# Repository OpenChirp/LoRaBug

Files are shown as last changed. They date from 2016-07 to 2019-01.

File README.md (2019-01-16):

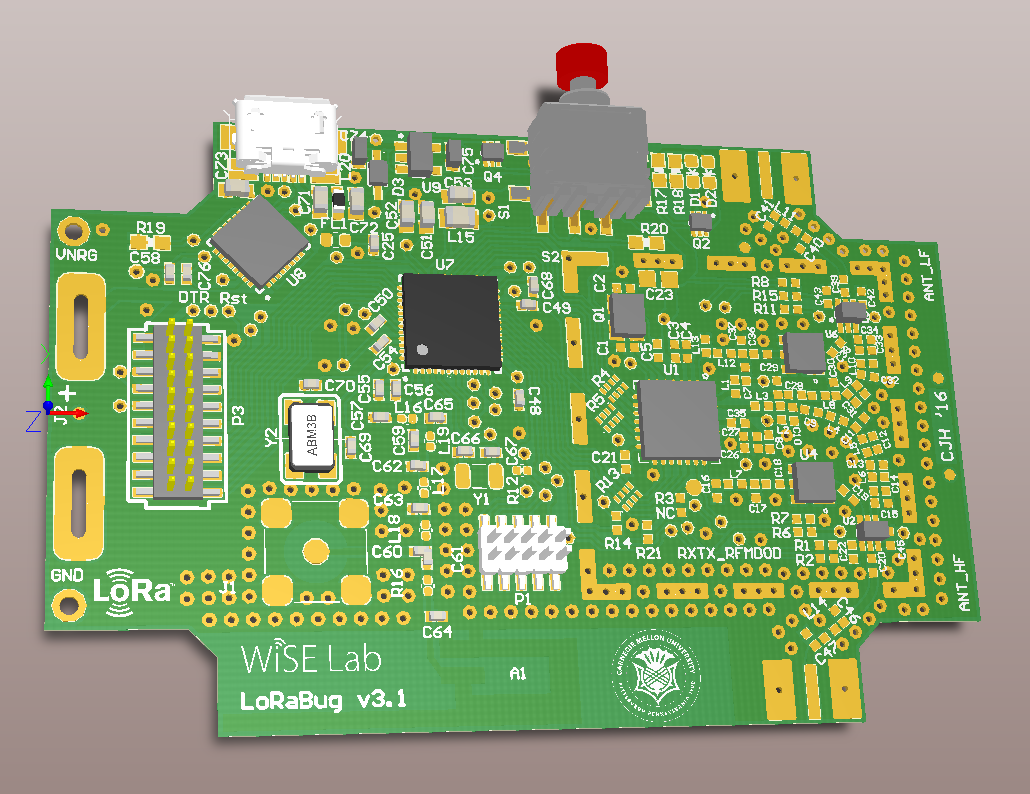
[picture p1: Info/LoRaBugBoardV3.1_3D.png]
LoRaBugBoard V3.1 3D Picture


# Specs
* TI CC2650 MCU with BLE and 802.15.4 support
* SX1276 LoRa radio
* Provide 500mA 3.3V (3.3-3.4V) from USB.

# Board Details
* Pin mappings are detailed in the spreadsheet found [here](https://docs.google.com/spreadsheets/d/1lk55i37ZrpTx_7zy1oA4uAmHo3XsjOCir2L95xEN9fU/edit?usp=sharing).
* Board physical dimensions and header placement can be found [here](https://docs.google.com/drawings/d/1snO6Dwncqp3OL73APsFgQn0SESudZwlPjw8W5KeOZVo/edit?usp=sharing).
* You can find other information, such as the schematic and board renderings, in the [Info](Info/) directory.

# Firmware Notes
* You can detect the presence of a USB by checking if the FTDI TX and RX
  pins are high. When the FTDI chip is activated, it pulls the TX and RX
  lines high.
  Additionally, this means the CC2650 should use push/pull and no pull-ups 
  when communicating with the FTDI.

# Info
* The power supported by the USB is limited by the 500mA limit of diode D3 and the 600mA limit of the voltage regulator U9.
* When using USB power, the 3.3V rail may swing to 3.4V. This is due to the linear regulator's ground pin voltage being raised by the inline mosfet Q4.
* The SX1276 is said to be only able to support PA_BOOST +20dBm TX when the input voltage is greater than 2.4V. See section 5.4.3 in the [SX1276 datasheet][sx1276_datasheet].

# Low Power Profile
Other than the reverse leakage current, these values are totally unconfirmed. The values are pulled straight from the [datasheet][sx1276_datasheet].

* Reverse leakage from battery through voltage regulation circuitry has shown to draw upwards of **80 nA**. Based on the datasheets, there is a possibility of 0.1 - 0.2uA draw.
* [CC2650][cc2650_overview]
    - Normal operation between 1.8 V and 3.8 V
    - The main MCU crystal is 24 MHz, which is doubled internally. There is also a 32 kHz clock for BLE. See section 6.9 in [overview datasheet][cc2650_brief_datasheet].
    - Active-Mode draws **61 uA/MHz**
    - Active-Mode Sensor Controller draws **8.2 uA/MHz**
    - Standby draws **1 uA** (RTC Running and RAM/CPU Retention)
    - Shutdown draws **100 nA** (Wake Up on External Events)
    - Active-Mode RX draws **5.9 mA**
    - Active-Mode TX at 0 dBm draws **6.1 mA**
    - Active-Mode TX at +5dBm draws **9.1 mA**
    - The sensor controller(when cpu freq. scalled) consumes less power than the [MSP430G2X][msp430_overview], which consumes 220 uA/MHz in active-mode and 0.7 uA in RTC mode.
* [SX1276][sx1276_overview]
    - Up to +17 dBm of RF output power which is maintained from 1.8 V to 3.7 V and +20 dBm from 2.4 V to 3.7 V. See section 5.1 of [datasheet][sx1276_datasheet].
    - We have PA_BOOST connected to the HF (high frequency) side antenna. This means we output 915MHz HF signals through PA_BOOST.
    - LoRa HF RX mode draws **10.3 mA**(125kHz bw) or **12.6 mA**(500kHz bw) with LNABoost off. See sections 2.5.1 and 2.5.5 of [datasheet][sx1276_datasheet].
    - LoRa HF TX mode draws around **90 mA** for +17dBm PA_BOOST and somewhere around **120 mA** for +20dBm PA_BOOST.
    - Sleep mode draws **0.2 uA**
    - Idle mode (RC oscillator enabled) draw **1.5 uA**
    - Standby mode (Crystal oscillator enabled) draw **1.6 mA**

# Changelog
* V3.1
    - Removed inverter and pullup/pulldown resistors from LoRa radio module for power saving
    - Mapped RF_CTRL1 and RF_CTRL2 as complement control pair for RF switches for power saving
    - Resolved SX1276 crystal caps manufacturing issue
* V3
    - Changed IO header to a 20pin 1.27mm for ease of use
    - Access to VCC_NREG, the power feeding the onboard regulator
    - Active low button
    - FTDI TX/RX lines pulled into header
    - Removed onboard I2C resistors
* V2
    - Fixed button NC/NO leads. Pulldown now pulls the signal low as initially designed.
    - Fixed leakage current through the linear regulator
    - Changed FTDI footprint to have longer leads for hand soldering
    - Used a single dual N-channel mosfet chip to control LEDs
    - Changed the fiducial location
    - Changed some components to consolidate count
* V1 - Initial Release

# Contribution Info

## Generating Manufacturer Files
To generate the manufacturer files for APCircuits.com, you need to generate the Gerbers(with outline), Aperture file, and NC Drill file.

To generate the gerbers and aperture files, do the following:
1. Click File -> Fabrication Output -> Gerber Files, when viewing a PCB Layout.
2. Make sure that Top Overlay, Top Paste, Top Solder, Top Layer, Bottom Layer, Bottom Solder, Bottom Overlay(optional), and Mechanical 1 are selected in the Layers tab.
3. Do not have anything selected in the Drill Drawing tab, and make sure that "Embedded aperture (RS274X)" is selected in the Aperture tab.
4. Press Ok.

To generate the NC Drill File, do the following:
1. Click File -> Fabrication Output -> NC Drill Files, when viewing a PCB Layout.
2. Just click Ok to the default settings.

To generate the pick and place coordinates file:
1. Click File -> Assembly Outputs -> Generate pick and place files
2. Ensure only the Text and Imperial options are checked and click Ok

The previous operations place all the output files in the "Project Output for LoRaBugBoard" directory.
You now just need to combine the following list of file into a zip archive. Make sure to copy in the
README.txt from previous archives.

Archive File List:

* PCBFireflyCaseV3.apr
* PCBFireflyCaseV3.DRR
* PCBFireflyCaseV3.GBL
* PCBFireflyCaseV3.GBO
* PCBFireflyCaseV3.GBS
* PCBFireflyCaseV3.GM1
* PCBFireflyCaseV3.GTL
* PCBFireflyCaseV3.GTO
* PCBFireflyCaseV3.GTP
* PCBFireflyCaseV3.GTS
* PCBFireflyCaseV3-RoundHoles.TXT
* PCBFireflyCaseV3-SlotHoles.TXT
* Pick Place for PCBFireflyCaseV3.txt
* README.txt

## Testing the Hardware
* ***Test FTDI, System UART, Bootloader Backdoor Trigger, and Onboard Voltage Regulator***
  Ensure that the bootloader backdoor is configured to use the button. Ensure R20 is low enough to not trigger the bootloader after reset.
  I previously had an issue where the pulldow(at the time) wasn't strong enough. Next, ensure you can actually enter the bootloader during reset.
  To aid in this, I created a script called [trigger_bootloader.sh](Info/trigger_bootloader.sh) in the Info directory that sends the initialization
  bytes to serial repeatedly. If you cat the serial device at the same time, you should see the bootloader respond.
  Maybe do a `stty -F /dev/ttyUSB0 115200 && cat /dev/ttyUSB0 | hd`. Checkout the [CC2650 Bootloader Spec][cc2650_bootloader_spec].
* ***Test LEDs***
* ***Test Pins in GPIO Hedaer***
* ***Test Debugging CC2650 Over Cortex Debug Header***
* ***Test SX1276 Front End***

# Antennas

| Description | Part Name | Manufacturer | Connector |
| ---| --- | --- | --- |
| Standard yellow 915MHz LoRa 5.591" 1.2dBi | [NT-916-CW-HWR-SMA](http://www.linxtechnologies.com/resources/data-guides/ant-916-cw-hwr.pdf) | Linx Technologies | SMA-Male |
| ~~4.256" 900MHz 3.0dBi~~ | ~~[APAMS-118](http://abracon.com/external-antenna/APAMS-118.pdf)~~ | ~~Abracon LLC~~ | ~~SMA-Male~~ |

# Accessories

The board was designed to accept an **RFI shield** over the LoRa radio components.
You can solder on a static can or use the two part removable can.
* Static can [BMI-S-103](http://www.digikey.com/products/en?keywords=BMI-S-103). The preferred low-profile can is the BMI-S-111 by Laird.
* Removable two part: The frame is [BMI-S-203-F](http://www.digikey.com/products/en?keywords=BMI-S-203-F) and the cover is [BMI-S-203-C](http://www.digikey.com/products/en?keywords=BMI-S-203-C).
* You can use a 10pin 1.27mm female-to-female IDC cable to connect the CC2650 Launchpad debugger.
  One such cable is the [Harwin M50 Female-to-Female](https://www.digikey.com/product-detail/en/harwin-inc/M50-9100542/952-2568-ND/4953091) cable.
* The SensorBug board uses a Tag-Connect TC2030 pin interface to pass JTAG through to the LoRaBug.
  You can use the [TC2030-CTX](http://www.tag-connect.com/TC2030-CTX) cable to connect the
  CC2650 Launchpad debugger.

The I/O header is a standard 1.27mm 2x10 pin header.
You can use the [Harwin M50-3121045](http://www.digikey.com/products/en?keywords=M50-3121045) to interface with it.

[cc2650_overview]: http://www.ti.com/product/CC2650
[cc2650_brief_datasheet]: http://www.ti.com/lit/ds/symlink/cc2650.pdf
[sx1276_overview]: http://www.semtech.com/wireless-rf/rf-transceivers/sx1276/
[sx1276_datasheet]: http://www.semtech.com/images/datasheet/sx1276_77_78_79.pdf
[msp430_overview]: http://www.ti.com/lsds/ti/microcontrollers_16-bit_32-bit/msp/ultra-low_power/msp430g2x_i2x/overview.page
[cc2650_bootloader_spec]: http://www.ti.com/lit/an/swra466a/swra466a.pdf

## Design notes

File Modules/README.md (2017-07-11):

# Description
This directory contains contributed extension modules for the LoRaBug.

| Module | Description | Author |
|---|---|---|
| [RGBW IO Board](LoRaBUG_RGBW_DaughterBoard) | High-power 12V RGBW LED Strip Controller with buttons and RGB LED | [Artur Balanuta](https://github.com/ABalanuta) |
| [SensorBug Board](SensorBug) | Environmental sensor board with a Grid-EYE IR sensor array | [Abhinand Sukumar](https://github.com/abhinans) |

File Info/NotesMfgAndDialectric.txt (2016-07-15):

Trace Thickness:      1       oz/ft^2
Substrate Height:     62      mil
Trace Width:          113.25  mil
Substrate dialectric: 4.58    
Impedance:            50Ohms

1oz/ft^2 == 1.4mil == 35.6um

####### AP Circuits #########

Drill Sizes
------------------------
Inch :(in mils) :x1.75
------------------------
.0200 (20   mil) 35
.0280 (28   mil) 49
.0350 (35   mil) 61.25
.0380 (38   mil) 66.5
.0420 (42   mil) 73.5
.0520 (52   mil) 91
.0595 (59.5 mil) 104.125
.0860 (86   mil) 150.5
.1250 (125  mil) 218.75
.1520 (152  mil) 266

BMI-S-103
BMI-S-203-F 26.21X26.21 (2PARTS)

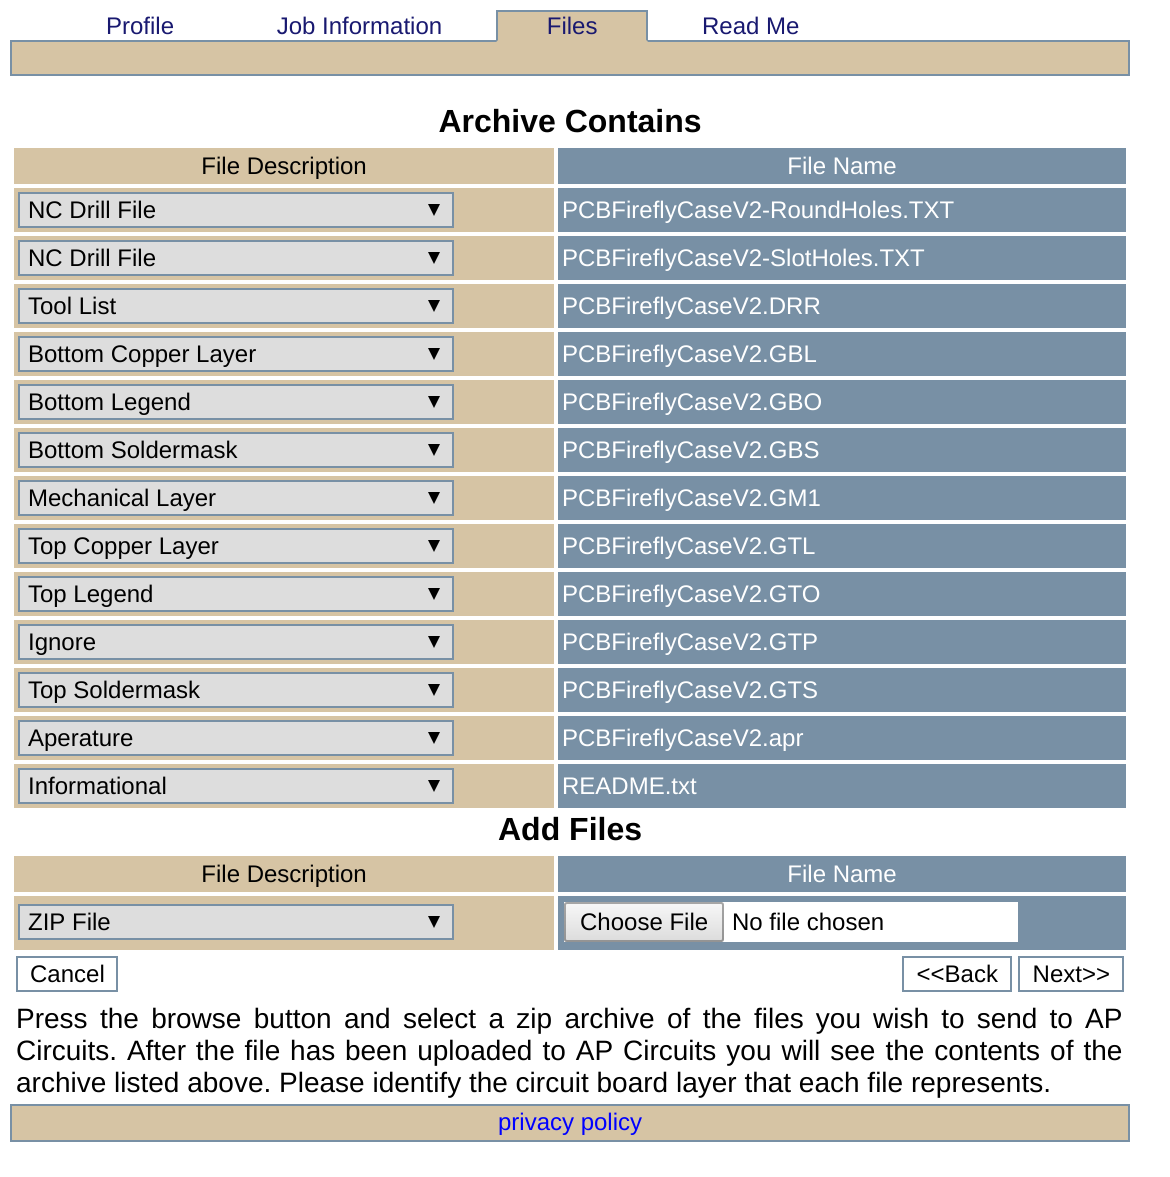
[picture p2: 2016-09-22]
Info/APCircuitsFiles.png

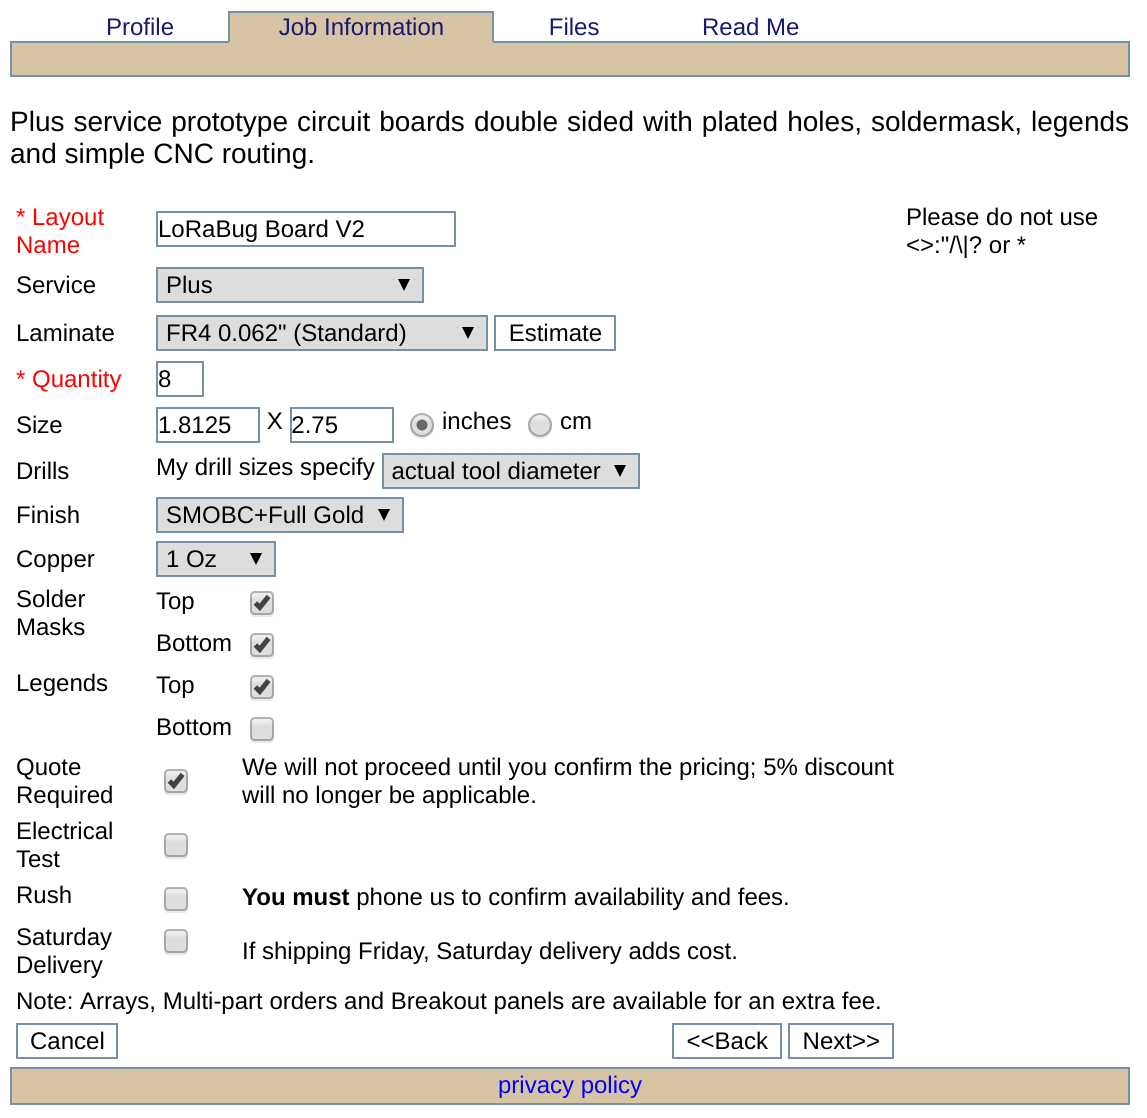
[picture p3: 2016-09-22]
Info/APCircuitsJobInformation.png

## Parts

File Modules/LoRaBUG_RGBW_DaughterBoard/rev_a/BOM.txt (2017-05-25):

Description			URL
LED RGB DIFFUSED 4SMD		https://www.digikey.com/product-detail/en/cree-inc/CLMVB-FKA-CFHEHLCBB7A363/CLMVB-FKA-CFHEHLCBB7A363CT-ND/6138627
Debug Connector Female		https://www.digikey.com/product-detail/en/harwin-inc/M50-3100545/952-1798-ND/3727767
Debug Connector Male		https://www.digikey.com/product-detail/en/harwin-inc/M50-3600542/952-1389-ND/2264370
475 Ohm Resistor 0603		https://www.digikey.com/product-detail/en/panasonic-electronic-components/ERJ-PA3J471V/P470BZCT-ND/5036331
10uF 0603 10V			https://www.digikey.com/product-detail/en/murata-electronics-north-america/GRM188R61A106KE69J/490-14372-1-ND/6606833
10uF 0603 25V			https://www.digikey.com/product-detail/en/murata-electronics-north-america/GRM188R61E106MA73D/490-7202-1-ND/3900486
MOSFET 2N-CH 30V 40A		https://www.digikey.com/product-detail/en/nexperia-usa-inc/BUK9K5R1-30EX/1727-2468-1-ND/5725903
IC REG LDO 3.3V 1A SOT223	https://www.digikey.com/product-detail/en/richtek-usa-inc/RT9164A-33GG/1028-1063-1-ND/3077883
DIODE SCHOTTKY 30V 500MA SOD323	https://www.digikey.com/product-detail/en/on-semiconductor/NSR0530HT1G/NSR0530HT1GOSCT-ND/5761654
SWITCH TACT SPST-NO 0.02A 12V 3.30mm x 3.10mm	https://www.digikey.com/product-detail/en/citizen/LS38G5-T/1642-1315-1-ND/5820730
CONN 6POS 2.54MM SES 		https://www.digikey.com/product-detail/en/te-connectivity-amp-connectors/1-2834016-6/A123832-ND/5872948
CONN 5.0MM SIDE ENTRY MSC 2P_GY	https://www.digikey.com/product-detail/en/te-connectivity-amp-connectors/2834095-1/A124212-ND/6012659
CONN RCPT 10POS SMD 1.27MM GOLD	https://www.digikey.com/product-detail/en/harwin-inc/M50-3100545/952-1798-ND/3727767
CONN HDR 1.27MM SMD AU 10POS	https://www.digikey.com/product-detail/en/harwin-inc/M50-3600542/952-1389-ND/2264370

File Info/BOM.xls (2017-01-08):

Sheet: Main, Power, and Peripherals
Identifier | Value | Geometry | Quantity | Description | Manufacturer Part Number | Manufacturer | Notes
PERIPH Q2 MAIN Q4 |  | SOT-563, SOT-666 | 2 | MOSFET 2N-CH 60V 0.1A SSMINI6 | FC6946010R | PANASONIC ELECTRONIC COMPONENTS (VA)
PERIPH D1 GREEN |  | 0603 | 1 | LED GREEN CLEAR 0603 SMD | 150060GS75000 | WURTH ELECTRONICS INC (VA)
PERIPH D2 RED |  | 0603 | 1 | LED RED CLEAR 0603 SMD | 150060RS75000 | WURTH ELECTRONICS INC (VA)
PWR D3 |  | SC-79, SOD-523 | 1 | DIODE SCHOTTKY 45V 750MA SC79-2 | BAS 52-02V H6327 | Infineon Technologies | 60-80 nA reverse leakage, but $0.47. Check Part Options for more choices
PERIPH S1 |  |  | 1 | SWITCH PUSH SPDT 0.4VA 28V | G3B15AH-XC | NKK SWITCHES
PERIPH P3 |  |  | 1 | Header 1.27mm 2x5 SMT Low-Profile | M50-3601042 | Harwin Inc. | New for V3
PWR U9 |  | SC-74A, SOT-753 | 1 | IC REG LDO 3.3V 0.6A SOT-25 | AP7365-33WG-7 | DIODES INCORPORATED (VA)
MAIN C76 (arduino rst) | 100pF | 0402 | DNM | CAP CER 100PF 50V NP0 0402 | GRM1555C1H101JA01D | MURATA ELECTRONICS (VA) | Use when you want an Arduino style reset when USB serial session starts
PWR C74 C75 | 1uF | 0603 | 2 | CAP CER 1UF 16V X5R 0603 | GRM188R61C105KA93D | MURATA ELECTRONICS (VA)
PERIPH R18 75OHM (Green LED D1) | 75 | 0603 | 1 | RES SMD 75 OHM 5% 1/10W 0603 | RC0603JR-0775RL | YAGEO (VA)
PERIPH R17 100OHM (Red LED D2) | 100 | 0603 | 1 | RES SMD 100 OHM 5% 1/10W 0603 | RC0603FR-07100RL | YAGEO (VA)
PERIPH R20 | 2.7K | 0603 | 1 | RES SMD 2.7K OHM 5% 1/10W 0603 | RMCF0603JT2K70 | STACKPOLE ELECTRONICS INC (VA) | Used to pull button high for bootloader backdoor trigger
PWR R19 | 47K | 0603 | 1 | RES SMD 47K OHM 5% 1/10W 0603 | RMCF0603JT47K0 | STACKPOLE ELECTRONICS INC (VA)

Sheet: FTDI
Identifier | Value | Geometry | Quantity | Description | Manufacturer Part Number | Manufacturer | Notes
FTDI U8 |  | 32-QFN | 1 | IC USB FS SERIAL UART 32-QFN | FT232RQ-REEL | FTDI (VA)
FTDI P2 (USB) |  |  | 1 | CONN USB MICRO B RECPT SMT R/A | 10118192-0001LF | AMPHENOL FCI (VA)
FTDI L20 (FERRITE) |  | 0603 | 1 | FERRITE BEAD 62 OHM 0603 1LN | 782633620 | WURTH ELECTRONICS INC (VA)
FTDI C71 C72 C73 | 100pF | 0603 | 3 | CAP CER 100PF 50V NP0 0603 | C0603C101J5GACTU | KEMET (VA)

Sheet: LoRa Radio Module Sorted
Identifier | Value | Geometry | Quantity | Description | Manufacturer Part Number | Manufacturer | Notes
ANT_HF ANT_LF |  | SMA End Launch 50 Ohms | 1 | SMA End launch jack receptacle for PCB mount Emerson Network | 142-0711-821 | Power | Only need 1 for 915MHz HF side
U4 U6 | 0R | 603 | 2 | Thick Film Resistor ±5%, 1/10W | CRCW06030000Z0EA | Vishay/Dale
R4 R5 R13 | 100R | EXB28V | 3 | SMD Resistor Array Resistors (4x), ±5%, 31mW | EXB-N8V101JX | Panasonic - ECG
R14 | 100R | 402 | 1 | Thick Film Resistor ±5%, 1/16W | CRCW0402100RJNED | Vishay/Dale
R2 R6 R11 R15 | 1k | 402 | 4 | Thick Film Resistor ±5%, 1/16W | CRCW04021K00JNED | Vishay/Dale
C1 C2 | 15pF | 402 | 2 | Multilayer ceramic capacitors C0G ±5%, 50V for Rakon Crystal (18pF for NDK) | GRM1555C1H150JA01D | Murata | Changed back to 15pF from 10pF, since 10pF does not work
C3 C4 C5 C21 C27 | 100nF | 402 | 5 | Multilayer ceramic capacitors X7R ±10%, 16V | GRM155R71C104KA88D | Murata
C10 C11 C29 | 8.2pF | 402 | 3 | Multilayer ceramic capacitors C0G ±5%, 50V | GRM1555C1H8R2CA01D | Murata
C7 | 100pF | 402 | 1 | Multilayer ceramic capacitors C0G ±5%, 50V | GRM1555C1H101JA01D | Murata
C32 | 12pF | 402 | 1 | Multilayer ceramic capacitors C0G ±5%, 50V | GRM1555C1H120JA01D | Murata
C30 | 15pF | 402 | 1 | Multilayer ceramic capacitors C0G ±5%, 50V | GRM1555C1H150JA01D | Murata
C12 | 1.5pF | 402 | 1 | Multilayer ceramic capacitors C0G ±0.25pF, 50V | GRM1555C1H1R5CA01D | Murata
C9 | 22pF | 402 | 1 | Multilayer ceramic capacitors C0G ±5%, 50V | GRM1555C1H220FA01D | Murata
C31 | 2.7pF | 402 | 1 | Multilayer ceramic capacitors C0G ±0.25pF, 50V | GRM1555C1H2R7CA01D | Murata
C13 C17 | 3.3pF | 402 | 2 | Multilayer ceramic capacitors C0G ±0.25pF, 50V | GRM1555C1H3R3CA01D | Murata
C8 C18 C19 C20 C26 C28 C36 C38 C39 | 47pF | 402 | 9 | Multilayer ceramic capacitors C0G ±5%, 50V | GRM1555C1H470JA01D | Murata
C34 | 4.7pF | 402 | 1 | Multilayer ceramic capacitors C0G ±0.25pF, 50V | GRM1555C1H4R7CA01D | Murata
C35 | 10nF | 402 | 1 | Multilayer ceramic capacitors X7R ±10%, 25V | GRM155R71E103KA01D | Murata
C22 C42 C43 C45 | 1nF | 402 | 4 | Multilayer ceramic capacitors X7R ±5%, 50V | GRM155R71H102JA01D | Murata
C23 | 10uF | 805 | 1 | Multilayer ceramic capacitors X5R ±10%, 10V | GRM21BR61A106KE19L | Murata
L1 | 47nH | 402 | 1 | Multilayer Inductor ±5% | LQG15HS47NJ02D | Murata
L2 | 33nH | 402 | 1 | Wirewound Inductor ±5% | LQW15AN33NJ00D | Murata
L3 | 2.2nH | 402 | 1 | Wirewound Inductor ±0.2nH | LQW15AN2N2C10D | Murata
L4 | 5.6nH | 402 | 1 | Wirewound Inductor ±0.2nH | LQW15AN5N6C10D | Murata
L5 | 4.7nH | 402 | 1 | Wirewound Inductor ±0.2nH | LQW15AN4N7C00D | Murata
L7 | 10nH | 402 | 1 | Multilayer Inductor ±5% | LQG15HS10NJ02D | Murata
L8 | 22nH | 402 | 1 | Wirewound Inductor ±5% | LQG15HS22NJ02D | Murata
L9 | 12nH | 402 | 1 | Wirewound Inductor ±5% | LQG15HS12NJ02D | Murata
L10 L13 | 18nH | 402 | 2 | Wirewound Inductor ±5% | LQG15HS18NJ02D | Murata
L12 | 4.7pF | 402 | 1 | Multilayer ceramic capacitors C0G ±0.25pF, 50V | GRM1555C1H4R7CA01D | Murata
L6 L11 L14 | 0R | 402 | 3 | Thick Film Resistor ±5%, 1/16W | CRCW04020000Z0ED | Vishay/Dale
U2 U5 | - | SC-70 | 2 | PE4259 - 10MHz to 3GHz SPDT RF Switch | PE4259 | Peregrine Semi
U1 | SX1276 | TQFN-28 6x6m | 1 | 137MHz to 1020MHz Low Power Long Range Transceiver | SX1276IMLTRT | Semtech
Q1 |  | QESM07 3.2x2.5mm 32.000MHz | - | Crystal unit Taitien; Tol. ±10ppm, Cload=10pF, G-Senstivity=2ppb/G max | S0197-X-002-3 | Taitien
Q1 |  | NX2520SA 2.5x2.0mm 32.000MHz | 1 | Crystal unit NDK; Tol. ±10ppm, Cload=10pF, G-Senstivity=2ppb/G max | NX2520SA-32.000000MHZ | NDK
Q1 |  | NX2016SA 2.0x1.6mm 32.000MHz | - | Crystal unit NDK; Tol. ±10ppm, Cload=10pF, G-Senstivity=2ppb/G max (recommended for new design) | EXS00A-CS06465 | NDK
Q1 |  | QESM07 3.2x2.5mm 32.000MHz | - | Crystal unit Rakon; Tol. ±10ppm, Cload=10pF, G-Senstivity=2ppb/G max (populated) | FTR5092-A2 | Rakon
Q1 |  | QESM09 2.0x1.6mm 32.000MHz | - | Crystal unit Rakon; Tol. ±10ppm, Cload=10pF, G-Senstivity=2ppb/G max (recommended for new design) | FTR5123-A0 | Rakon

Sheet: TI CC2650 MCU Module
Identifier | Value | Geometry | Quantity | Description | Manufacturer Part Number | Manufacturer | Part Number | RoHS Status | Notes
C25 | DNM | 0402 | 0 | CAPACITOR, DO NOT MOUNT, 0402, SMD |  |  | 02-01324
C48 C49 C50 C54 C55 C58 | 100nF | 0402 | 6 | CAPACITOR, CERAMIC X7R, 100nF, 6.3V, -10%/+10%, -55DEGC/+125DEGC, 0402, SMD | GRM155R70J104KA01D | MURATA | 02-02323 | ROHS_COMPLIANT
C51 C53 | 10uF | 0603 | 2 | CAPACITOR, CERAMIC X5R, 10uF, 6.3V, -20%/+20%, -55DEGC/+85DEGC, 0603, SMD | GRM188R60J106ME47D | MURATA | 02-02419 | ROHS_COMPLIANT
C52 | 100nF | 0603 | 1 | CAPACITOR, CERAMIC X7R, 100nF, 25V, -10%/+10%, -55DEGC/+125DEGC, 0603, SMD | GRM188R71E104KA01D | MURATA | 02-01992 | ROHS_COMPLIANT
C56 C60 C62 C64 C69 C70 | DNM | 0402 | 0 | CAPACITOR, CERAMIC, N/A VALUE, -55DEGC/+125DEGC, 0402, SMD | CAPACITOR_0402_DNM_N/A_M | Manufacturer selection | 02-04164 | PART NOT KNOWN
C59 C63 C65 | 1pF | 0402 | 3 | CAPACITOR, CERAMIC C0G/NP0, 1pF, 50V, -0.25pF/ +0.25pF, -55DEGC/+125DEGC, 0402, SMD | GRM1555C1H1R0CA01D | MURATA | 02-04672 | ROHS_COMPLIANT
C61 | 12pF | 0402 | 1 | CAPACITOR, CERAMIC C0G/NP0, 12pF, 50V, -5%/+5%, -55DEGC/+125DEGC, 0402, SMD | GRM1555C1H120JA01D | MURATA | 02-04168 | ROHS_COMPLIANT
C66 C67 | 12pF | 0402 | 2 | CAPACITOR, CERAMIC C0G/NP0, 12pF, 50V, -5%/+5%, -55DEGC/+125DEGC, 0402, SMD | CAPACITOR_0402_12pF_C0G/NP0_M_+/-5%_50V | MANUFACTURER SELECTION | 02-03030 | ROHS_COMPLIANT | Caps for crystal Y1
C68 | 1uF | 0402 | 1 | CAPACITOR, CERAMIC X5R, 1uF, 10V, -10%/+10%, -55DEGC/+85DEGC, 0402, SMD | GRM155R61A105KE15D | MURATA | 02-02381 | ROHS_COMPLIANT
C57 | 6.8pF | 0402 | 1 | CAPACITOR, CERAMIC C0G/NP0, 6.8pF, 50V, -0.25pF, +0.25pF, -55DEGC/+125DEGC, 0402, SMD | GRM1555C1H6R8CA01D | MURATA | 02-04169 | ROHS_COMPLIANT
FL1 | BLM18HE152SN1 | 0603 | 1 | FILTER, EMI, 1500@100MHz, -55DEGC/+125DEGC, 0603, SMD | BLM18HE152SN1D | MURATA | 04-00470 | ROHS_COMPLIANT
J1 | DNM |  | 0 | CONNECTOR, COAX RF, STRAIGHT, FEMALE, 1 PIN, SMD | SMA-10V21-TGG | HUS-TSAN | 06-02188 | N/A
L15 | 10uH | 0805 | 1 | INDUCTOR, CHIP, 10uH, -20%/+20%, 0.11A, -40DEGC/+85DEGC, 0805, SMD | CKS2125100M-T | TAIYO YUDEN | 03-06514 | ROHS_COMPLIANT
L16 L19 | 2.4nH | 0402 | 2 | INDUCTOR, CHIP, 2.4nH, -0.3nH/+0.3nH, 0.3A, -55DEGC/+125DEGC, 0402, SMD | LQG15HN2N4S02D | MURATA | 03-06554 | ROHS_COMPLIANT
L17 L18 | 2nH | 0402 | 2 | INDUCTOR, CHIP, 2nH, -0.3nH/ +0.3nH, 0.3A, -55DEGC/+125DEGC, 0402, SMD | LQG15HS2N0S02D | MURATA | 03-06525 | ROHS_COMPLIANT
R12 | 100k | 0402 | 1 | RESISTOR, THICK FILM, 100k, -1%/+1%, 0.063W, 50V, -55DEGC/+155DEGC, 0402, SMD | RESISTOR_0402_100k_+/-1%_50V_0.063W_M_+/-100PPM | MANUFACTURER SELECTION | 01-12837 | ROHS_COMPLIANT
R16 | 0 | 0402 | 1 | RESISTOR, JUMPER, -55DEGC/+155DEGC, 0402, SMD | RK73Z1ETTP | KOA SPEER | 01-01784 | ROHS_COMPLIANT
U7 | CC2650F128RGZ | QFN48 | 1 | IC, DIGITAL, 2.4GHZ SIMPLELINK WIRELESS MCU, PITCH 0,5MM, QFN48, SMD | CC2650F128RGZR | TEXAS INSTRUMENTS | 18-28499 | ROHS_COMPLIANT | Only difference between the RGZT and RGZR is package qty from TI. T=250 R=2500
Y1 | 32.768kHz |  | 1 | CRYSTAL, RESONATOR, 32.768kHz, -20PPM/+20PPM, -40DEGC/+85DEGC, SMD | FC-135 32.7680KA-AG0 | EPSON | 12-00546 | ROHS_COMPLIANT
Y2 | 24MHz |  | 1 | 24MHz ±10ppm Crystal 10pF 50 Ohm -10°C ~ 60°C Surface Mount 4-SMD, No Lead (DFN, LCC) | ABM3B-24.000MHZ-10-1-U-T | ABRACON LLC |  |  | More precise crystal from Patrick’s design
P1 | Cortex Debug Header |  | 1 | SMD Cortex Debug Header Without Shroud | 20021121-00010C4LF | Amphenol FCI |  | ROHS_COMPLIANT

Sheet: Hardware
Identifier | Value | Geometry | Quantity | Description | Manufacturer Part Number | Manufacturer | Notes
Antenna HF_ANT |  |  | 1 | Standard Yellow Ended LoRa Antennas 1.2dBi 5.591” | ANT-916-CW-HWR-SMA | Linx Technologies | Standard Yellow Tipped LoRa Antenna
Enclosure |  |  | 1 | Enclosures, Boxes, & Cases Mini ABS White w/AA BattComp 3x2.1x1.2" | S1A-302112 | New Age Enclosures | Mouser.com OR from NewAgeEnclosures company with milling
Light Pipe Small |  |  | 1
Light Pipe Big |  |  | 1
Environment Sensor Board |  |  | 1
AA Batteries |  |  | 2
RFI Can |  |  | 1 | Static solder on can | BMI-S-103 | Laird Technologies EMI
RFI Can Frame |  |  | 1 | Two piece can frame | BMI-S-203-F | Laird Technologies EMI
RFI Can Cover |  |  | 1 | Two piece can cover | BMI-S-203-C | Laird Technologies EMI
RFI Can – Low profile |  |  | 1 | Static solder on small 2mm height | BMI-S-111 | Laird Technologies EMI

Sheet: Part Options
Identifier | Value | Geometry | Quantity | Description | Manufacturer Part Number | Manufacturer | Notes
MAIN D3 |  | SC-90, SOD-323F | 1 | DIODE SCHOTTKY 20V 500MA SMINI2 | DB2J20900L | PANASONIC ELECTRONIC COMPONENTS (VA) | 5uA reverse leakage, but $0.10
MAIN D3 |  | SC-90, SOD-323F | 1 | DIODE SCHOTTKY 20V 500MA SMINI2 | DB2J20100L | PANASONIC ELECTRONIC COMPONENTS (VA) | 0.3uA reverse leakage, but $0.11
MAIN D3 |  | SC-79, SOD-523 | 1 | DIODE SCHOTTKY 45V 750MA SC79-2 | BAS 52-02V H6327 | Infineon Technologies | 0 measurable reverse leakage, but $0.47
HF_ANT |  |  | 1 | 3dBi 4.265” Rubber Antenna | APAMS-118 | Abracon LLC
HF_ANT |  |  | 1 | 2.5dBi 6.299" Wire Right Angle Antenna | S161AH-915R | Nearson Inc
Y2 | 24MHz |  | 1 | CRYSTAL, CRYSTAL OSCILLATOR, 24MHz, -15PPM/DEGC/+15PPM/DEGC, -40DEGC/+85DEGC, SMD | TSX-3225 24.0000MF15X-AC3 | EPSON | This Does Not Match Footprint On PCB, but is the recommended crystal from dev board. You can hand solder this on the footprint, tho.

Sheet: LoRa Radio Module - Digikey'd
Identifier | Manufacturer Part Number | Geometry | Value | Quantity | Description | Manufacturer
U2 | PE4259 | SC-70 | - | 1 | PE4259 - 10MHz to 3GHz SPDT RF Switch | Peregrine Semi
U3 | NC7SZ04P5X | SC-70-5 | - | 1 | NC7SZ04 TinyLogic UHS Inverter | Fairchild Semi
U5 | PE4259 | SC-70 | - | 1 | PE4259 - 10MHz to 3GHz SPDT RF Switch | Peregrine Semi
U4 | CRCW06030000Z0EA | 603 | 0R | 1 | Thick Film Resistor ±5%, 1/10W | Vishay/Dale
U6 | CRCW06030000Z0EA | 603 | 0R | 1 | Thick Film Resistor ±5%, 1/10W | Vishay/Dale
U1 | SX1276IMLTRT | TQFN-28 6x6m | SX1276 | 1 | 137MHz to 1020MHz Low Power Long Range Transceiver | Semtech
R2 | CRCW04021K00JNED | 402 | 1k | 1 | Thick Film Resistor ±5%, 1/16W | Vishay/Dale
R4 | EXB-N8V101JX | EXB28V | 100R | 1 | SMD Resistor Array Resistors (4x), ±5%, 31mW | Panasonic - ECG
R5 | EXB-N8V101JX | EXB28V | 100R | 1 | SMD Resistor Array Resistors (4x), ±5%, 31mW | Panasonic - ECG
R6 | CRCW04020000Z0ED | 402 | 0R | 1 | Thick Film Resistor ±5%, 1/16W | Vishay/Dale
R7 | CRCW04021K00JNED | 402 | 1k | 1 | Thick Film Resistor ±5%, 1/16W | Vishay/Dale
R10 | CRCW04024K70JNED | 402 | 4.7k | 1 | Thick Film Resistor ±5%, 1/16W | Vishay/Dale
R13 | EXB-N8V101JX | EXB28V | 100R | 1 | SMD Resistor Array Resistors (4x), ±5%, 31mW | Panasonic - ECG
R14 | CRCW0402100RJNED | 402 | 100R | 1 | Thick Film Resistor ±5%, 1/16W | Vishay/Dale
R21 | CRCW0402100RJNED | 402 | 100R | 1 | Thick Film Resistor ±5%, 1/16W | Vishay/Dale
C1 | GRM1555C1H150JA01D | 402 | 15pF | 1 | Multilayer ceramic capacitors C0G ±5%, 50V for Rakon Crystal (18pF for NDK) | Murata
C2 | GRM1555C1H150JA01D | 402 | 15pF | 1 | Multilayer ceramic capacitors C0G ±5%, 50V for Rakon Crystal (18pF for NDK) | Murata
C3 | GRM155R71C104KA88D | 402 | 100nF | 1 | Multilayer ceramic capacitors X7R ±10%, 16V | Murata
C4 | GRM155R71C104KA88D | 402 | 100nF | 1 | Multilayer ceramic capacitors X7R ±10%, 16V | Murata
C5 | GRM155R71C104KA88D | 402 | 100nF | 1 | Multilayer ceramic capacitors X7R ±10%, 16V | Murata
C6 | GRM155R71C104KA88D | 402 | 100nF | 1 | Multilayer ceramic capacitors X7R ±10%, 16V | Murata
C7 | GRM1555C1H101JA01D | 402 | 100pF | 1 | Multilayer ceramic capacitors C0G ±5%, 50V | Murata
C8 | GRM1555C1H470JA01D | 402 | 47pF | 1 | Multilayer ceramic capacitors C0G ±5%, 50V | Murata
C9 | GRM1555C1H220FA01D | 402 | 22pF | 1 | Multilayer ceramic capacitors C0G ±5%, 50V | Murata
C10 | GRM1555C1H8R2CA01D | 402 | 8.2pF | 1 | Multilayer ceramic capacitors C0G ±5%, 50V | Murata
C11 | GRM1555C1H8R2CA01D | 402 | 8.2pF | 1 | Multilayer ceramic capacitors C0G ±5%, 50V | Murata
C12 | GRM1555C1H1R5CA01D | 402 | 1.5pF | 1 | Multilayer ceramic capacitors C0G ±0.25pF, 50V | Murata
C13 | GRM1555C1H3R3CA01D | 402 | 3.3pF | 1 | Multilayer ceramic capacitors C0G ±0.25pF, 50V | Murata
C17 | GRM1555C1H3R3CA01D | 402 | 3.3pF | 1 | Multilayer ceramic capacitors C0G ±0.25pF, 50V | Murata
C18 | GRM1555C1H470JA01D | 402 | 47pF | 1 | Multilayer ceramic capacitors C0G ±5%, 50V | Murata
C19 | GRM1555C1H470JA01D | 402 | 47pF | 1 | Multilayer ceramic capacitors C0G ±5%, 50V | Murata
C20 | GRM1555C1H470JA01D | 402 | 47pF | 1 | Multilayer ceramic capacitors C0G ±5%, 50V | Murata
C21 | GRM155R71C104KA88D | 402 | 100nF | 1 | Multilayer ceramic capacitors X7R ±10%, 16V | Murata
C22 | GRM155R71H102JA01D | 402 | 1nF | 1 | Multilayer ceramic capacitors X7R ±5%, 50V | Murata
C23 | GRM21BR61A106KE19L | 805 | 10uF | 1 | Multilayer ceramic capacitors X5R ±10%, 10V | Murata
C26 | GRM1555C1H470JA01D | 402 | 47pF | 1 | Multilayer ceramic capacitors C0G ±5%, 50V | Murata
C27 | GRM155R71C104KA88D | 402 | 100nF | 1 | Multilayer ceramic capacitors X7R ±10%, 16V | Murata
C28 | GRM1555C1H470JA01D | 402 | 47pF | 1 | Multilayer ceramic capacitors C0G ±5%, 50V | Murata
C29 | GRM1555C1H8R2CA01D | 402 | 8.2pF | 1 | Multilayer ceramic capacitors C0G ±5%, 50V | Murata
C30 | GRM1555C1H150JA01D | 402 | 15pF | 1 | Multilayer ceramic capacitors C0G ±5%, 50V | Murata
C31 | GRM1555C1H2R7CA01D | 402 | 2.7pF | 1 | Multilayer ceramic capacitors C0G ±0.25pF, 50V | Murata
C32 | GRM1555C1H120JA01D | 402 | 12pF | 1 | Multilayer ceramic capacitors C0G ±5%, 50V | Murata
C34 | GRM1555C1H4R7CA01D | 402 | 4.7pF | 1 | Multilayer ceramic capacitors C0G ±0.25pF, 50V | Murata
C35 | GRM155R71E103KA01D | 402 | 10nF | 1 | Multilayer ceramic capacitors X7R ±10%, 25V | Murata
C36 | GRM1555C1H470JA01D | 402 | 47pF | 1 | Multilayer ceramic capacitors C0G ±5%, 50V | Murata
C38 | GRM1555C1H470JA01D | 402 | 47pF | 1 | Multilayer ceramic capacitors C0G ±5%, 50V | Murata
C39 | GRM1555C1H470JA01D | 402 | 47pF | 1 | Multilayer ceramic capacitors C0G ±5%, 50V | Murata
C42 | GRM155R71H102JA01D | 402 | 1nF | 1 | Multilayer ceramic capacitors X7R ±5%, 50V | Murata
C43 | GRM155R71H102JA01D | 402 | 1nF | 1 | Multilayer ceramic capacitors X7R ±5%, 50V | Murata
C45 | GRM155R71H102JA01D | 402 | 1nF | 1 | Multilayer ceramic capacitors X7R ±5%, 50V | Murata
L1 | LQG15HS47NJ02D | 402 | 47nH | 1 | Multilayer Inductor ±5% | Murata
L2 | LQW15AN33NJ00D | 402 | 33nH | 1 | Wirewound Inductor ±5% | Murata
L3 | LQW15AN2N2C10D | 402 | 2.2nH | 1 | Wirewound Inductor ±0.2nH | Murata
L4 | LQW15AN5N6C10D | 402 | 5.6nH | 1 | Wirewound Inductor ±0.2nH | Murata
L5 | LQW15AN4N7C00D | 402 | 4.7nH | 1 | Wirewound Inductor ±0.2nH | Murata
L6 | CRCW04020000Z0ED | 402 | 0R | 1 | Thick Film Resistor ±5%, 1/16W | Vishay/Dale
L7 | LQG15HS10NJ02D | 402 | 10nH | 1 | Multilayer Inductor ±5% | Murata
L8 | LQG15HS22NJ02D | 402 | 22nH | 1 | Wirewound Inductor ±5% | Murata
L9 | LQG15HS12NJ02D | 402 | 12nH | 1 | Wirewound Inductor ±5% | Murata
L10 | LQG15HS18NJ02D | 402 | 18nH | 1 | Wirewound Inductor ±5% | Murata
L11 | CRCW04020000Z0ED | 402 | 0R | 1 | Thick Film Resistor ±5%, 1/16W | Vishay/Dale
L12 | GRM1555C1H4R7CA01D | 402 | 4.7pF | 1 | Multilayer ceramic capacitors C0G ±0.25pF, 50V | Murata
L13 | LQG15HS18NJ02D | 402 | 18nH | 1 | Wirewound Inductor ±5% | Murata
L14 | CRCW04020000Z0ED | 402 | 0R | 1 | Thick Film Resistor ±5%, 1/16W | Vishay/Dale
Q1 | FTR5092-A2 | QESM07 3.2x2.5mm 32.000MHz |  | - | Crystal unit Rakon; Tol. ±10ppm, Cload=10pF, G-Senstivity=2ppb/G max (populated) | Rakon
Q1 | FTR5123-A0 | QESM09 2.0x1.6mm 32.000MHz |  | - | Crystal unit Rakon; Tol. ±10ppm, Cload=10pF, G-Senstivity=2ppb/G max (recommended for new design) | Rakon
Q1 | EXS00A-CS06465 | NX2016SA 2.0x1.6mm 32.000MHz |  | - | Crystal unit NDK; Tol. ±10ppm, Cload=10pF, G-Senstivity=2ppb/G max (recommended for new design) | NDK
Q1 | NX2520SA-32.000000MHZ | NX2520SA 2.5x2.0mm 32.000MHz |  | 1 | Crystal unit NDK; Tol. ±10ppm, Cload=10pF, G-Senstivity=2ppb/G max | NDK
Q1 | S0197-X-002-3 | QESM07 3.2x2.5mm 32.000MHz |  | - | Crystal unit Taitien; Tol. ±10ppm, Cload=10pF, G-Senstivity=2ppb/G max | Taitien
ANT_HF | 142-0711-821 | SMA End Launch 50 Ohms |  | 1 | SMA End launch jack receptacle for PCB mount Emerson Network | Power
ANT_LF | 142-0711-821 | SMA End Launch 50 Ohms |  | 1 | SMA End launch jack receptacle for PCB mount Emerson Network | Power

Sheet: LoRa Radio Module
Identifier | Part Number | Geometry | Value | Quantity | Description | Manufacturer
U1 | SX1276IMLTRT | TQFN-28 6x6m | SX1276 | 1 | 137MHz to 1020MHz Low Power Long Range Transceiver | Semtech
U2 | PE4259 | SC-70 | - | 1 | PE4259 - 10MHz to 3GHz SPDT RF Switch | Peregrine Semi
U3 | NC7SZ04P5X | SC-70-5 | - | 1 | NC7SZ04 TinyLogic UHS Inverter | Fairchild Semi
U4 | CRCW06030000Z0EA | 603 | 0R | 1 | Thick Film Resistor ±5%, 1/10W | Vishay/Dale
U5 | PE4259 | SC-70 | - | 1 | PE4259 - 10MHz to 3GHz SPDT RF Switch | Peregrine Semi
U6 | CRCW06030000Z0EA | 603 | 0R | 1 | Thick Film Resistor ±5%, 1/10W | Vishay/Dale
R2 | CRCW04021K00JNED | 402 | 1k | 1 | Thick Film Resistor ±5%, 1/16W | Vishay/Dale
R4 | EXB-N8V101JX | EXB28V | 100R | 1 | SMD Resistor Array Resistors (4x), ±5%, 31mW | Panasonic - ECG
R5 | EXB-N8V101JX | EXB28V | 100R | 1 | SMD Resistor Array Resistors (4x), ±5%, 31mW | Panasonic - ECG
R6 | CRCW04020000Z0ED | 402 | 0R | 1 | Thick Film Resistor ±5%, 1/16W | Vishay/Dale
R7 | CRCW04021K00JNED | 402 | 1k | 1 | Thick Film Resistor ±5%, 1/16W | Vishay/Dale
R10 | CRCW04024K70JNED | 402 | 4.7k | 1 | Thick Film Resistor ±5%, 1/16W | Vishay/Dale
R13 | EXB-N8V101JX | EXB28V | 100R | 1 | SMD Resistor Array Resistors (4x), ±5%, 31mW | Panasonic - ECG
R14 | CRCW0402100RJNED | 402 | 100R | 1 | Thick Film Resistor ±5%, 1/16W | Vishay/Dale
R21 | CRCW0402100RJNED | 402 | 100R | 1 | Thick Film Resistor ±5%, 1/16W | Vishay/Dale
C1 | GRM1555C1H150JA01D | 402 | 15pF | 1 | Multilayer ceramic capacitors C0G ±5%, 50V for Rakon Crystal (18pF for NDK) | Murata
C2 | GRM1555C1H150JA01D | 402 | 15pF | 1 | Multilayer ceramic capacitors C0G ±5%, 50V for Rakon Crystal (18pF for NDK) | Murata
C3 | GRM155R71C104KA88D | 402 | 100nF | 1 | Multilayer ceramic capacitors X7R ±10%, 16V | Murata
C4 | GRM155R71C104KA88D | 402 | 100nF | 1 | Multilayer ceramic capacitors X7R ±10%, 16V | Murata
C5 | GRM155R71C104KA88D | 402 | 100nF | 1 | Multilayer ceramic capacitors X7R ±10%, 16V | Murata
C6 | GRM155R71C104KA88D | 402 | 100nF | 1 | Multilayer ceramic capacitors X7R ±10%, 16V | Murata
C7 | GRM1555C1H101JZ01D | 402 | 100pF | 1 | Multilayer ceramic capacitors C0G ±5%, 50V | Murata
C8 | GRM1555C1H470JZ01D | 402 | 47pF | 1 | Multilayer ceramic capacitors C0G ±5%, 50V | Murata
C9 | GRM1555C1H220JZ01D | 402 | 22pF | 1 | Multilayer ceramic capacitors C0G ±5%, 50V | Murata
C10 | GRM1555C1H8R2CZ01D | 402 | 8.2pF | 1 | Multilayer ceramic capacitors C0G ±5%, 50V | Murata
C11 | GRM1555C1H8R2CZ01D | 402 | 8.2pF | 1 | Multilayer ceramic capacitors C0G ±5%, 50V | Murata
C12 | GRM1555C1H1R5CZ01D | 402 | 1.5pF | 1 | Multilayer ceramic capacitors C0G ±0.25pF, 50V | Murata
C13 | GRM1555C1H3R3CZ01D | 402 | 3.3pF | 1 | Multilayer ceramic capacitors C0G ±0.25pF, 50V | Murata
C17 | GRM1555C1H3R3CZ01D | 402 | 3.3pF | 1 | Multilayer ceramic capacitors C0G ±0.25pF, 50V | Murata
C18 | GRM1555C1H470JZ01D | 402 | 47pF | 1 | Multilayer ceramic capacitors C0G ±5%, 50V | Murata
C19 | GRM1555C1H470JZ01D | 402 | 47pF | 1 | Multilayer ceramic capacitors C0G ±5%, 50V | Murata
C20 | GRM1555C1H470JZ01D | 402 | 47pF | 1 | Multilayer ceramic capacitors C0G ±5%, 50V | Murata
C21 | GRM155R71C104KA88D | 402 | 100nF | 1 | Multilayer ceramic capacitors X7R ±10%, 16V | Murata
C22 | GRM155R71H102JA01D | 402 | 1nF | 1 | Multilayer ceramic capacitors X7R ±5%, 50V | Murata
C23 | GRM21BR61A106KE19L | 805 | 10uF | 1 | Multilayer ceramic capacitors X5R ±10%, 10V | Murata
C26 | GRM1555C1H470JZ01D | 402 | 47pF | 1 | Multilayer ceramic capacitors C0G ±5%, 50V | Murata
C27 | GRM155R71C104KA88D | 402 | 100nF | 1 | Multilayer ceramic capacitors X7R ±10%, 16V | Murata
C28 | GRM1555C1H470JZ01D | 402 | 47pF | 1 | Multilayer ceramic capacitors C0G ±5%, 50V | Murata
C29 | GRM1555C1H8R2CZ01D | 402 | 8.2pF | 1 | Multilayer ceramic capacitors C0G ±5%, 50V | Murata
C30 | GRM1555C1H150JA01D | 402 | 15pF | 1 | Multilayer ceramic capacitors C0G ±5%, 50V | Murata
C31 | GRM1555C1H2R7CZ01D | 402 | 2.7pF | 1 | Multilayer ceramic capacitors C0G ±0.25pF, 50V | Murata
C32 | GRM1555C1H120JZ01D | 402 | 12pF | 1 | Multilayer ceramic capacitors C0G ±5%, 50V | Murata
C34 | GRM1555C1H4R7CZ01D | 402 | 4.7pF | 1 | Multilayer ceramic capacitors C0G ±0.25pF, 50V | Murata
C35 | GRM155R71E103KA01D | 402 | 10nF | 1 | Multilayer ceramic capacitors X7R ±10%, 25V | Murata
C36 | GRM1555C1H470JZ01D | 402 | 47pF | 1 | Multilayer ceramic capacitors C0G ±5%, 50V | Murata
C38 | GRM1555C1H470JZ01D | 402 | 47pF | 1 | Multilayer ceramic capacitors C0G ±5%, 50V | Murata
C39 | GRM1555C1H470JZ01D | 402 | 47pF | 1 | Multilayer ceramic capacitors C0G ±5%, 50V | Murata
C42 | GRM155R71H102JA01D | 402 | 1nF | 1 | Multilayer ceramic capacitors X7R ±5%, 50V | Murata
C43 | GRM155R71H102JA01D | 402 | 1nF | 1 | Multilayer ceramic capacitors X7R ±5%, 50V | Murata
C45 | GRM155R71H102JA01D | 402 | 1nF | 1 | Multilayer ceramic capacitors X7R ±5%, 50V | Murata
L1 | LQG15HS47NJ02D | 402 | 47nH | 1 | Multilayer Inductor ±5% | Murata
L2 | LQW15AN33NJ00D | 402 | 33nH | 1 | Wirewound Inductor ±5% | Murata
L3 | LQW15AN2N2C10D | 402 | 2.2nH | 1 | Wirewound Inductor ±0.2nH | Murata
L4 | LQW15AN5N6C10D | 402 | 5.6nH | 1 | Wirewound Inductor ±0.2nH | Murata
L5 | LQW15AN4N7C00D | 402 | 4.7nH | 1 | Wirewound Inductor ±0.2nH | Murata
L6 | CRCW04020000Z0ED | 402 | 0R | 1 | Thick Film Resistor ±5%, 1/16W | Vishay/Dale
L7 | LQG15HS10NJ02D | 402 | 10nH | 1 | Multilayer Inductor ±5% | Murata
L8 | LQG15HS22NJ02D | 402 | 22nH | 1 | Wirewound Inductor ±5% | Murata
L9 | LQG15HS12NJ02D | 402 | 12nH | 1 | Wirewound Inductor ±5% | Murata
L10 | LQG15HS18NJ02D | 402 | 18nH | 1 | Wirewound Inductor ±5% | Murata
L11 | CRCW04020000Z0ED | 402 | 0R | 1 | Thick Film Resistor ±5%, 1/16W | Vishay/Dale
L12 | GRM1555C1H4R7CZ01D | 402 | 4.7pF | 1 | Multilayer ceramic capacitors C0G ±0.25pF, 50V | Murata
L13 | LQG15HS18NJ02D | 402 | 18nH | 1 | Wirewound Inductor ±5% | Murata
L14 | CRCW04020000Z0ED | 402 | 0R | 1 | Thick Film Resistor ±5%, 1/16W | Vishay/Dale
Q1 | FTR5092-A2 | QESM07 3.2x2.5mm 32.000MHz |  | 1 | Crystal unit Rakon; Tol. ±10ppm, Cload=10pF, G-Senstivity=2ppb/G max (populated) | Rakon
Q1 | FTR5123-A0 | QESM09 2.0x1.6mm 32.000MHz |  | - | Crystal unit Rakon; Tol. ±10ppm, Cload=10pF, G-Senstivity=2ppb/G max (recommended for new design) | Rakon
Q1 | EXS00A-CS06465 | NX2016SA 2.0x1.6mm 32.000MHz |  | - | Crystal unit NDK; Tol. ±10ppm, Cload=10pF, G-Senstivity=2ppb/G max (recommended for new design) | NDK
Q1 | EXS00A-CS00131 | NX2520SA 2.5x2.0mm 32.000MHz |  | - | Crystal unit NDK; Tol. ±10ppm, Cload=10pF, G-Senstivity=2ppb/G max | NDK
Q1 | S0197-X-002-3 | QESM07 3.2x2.5mm 32.000MHz |  | - | Crystal unit Taitien; Tol. ±10ppm, Cload=10pF, G-Senstivity=2ppb/G max | Taitien
ANT_HF | 142-0711-821 | SMA End Launch 50 Ohms |  | 1 | SMA End launch jack receptacle for PCB mount Emerson Network | Power
ANT_LF | 142-0711-821 | SMA End Launch 50 Ohms |  | 1 | SMA End launch jack receptacle for PCB mount Emerson Network | Power

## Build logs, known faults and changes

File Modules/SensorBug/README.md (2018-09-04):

# SensorBug

An environmental sensor board with a Grid-EYE IR sensor array

## Sensors

1. Panasonic Grid-EYE AMG8833
2. Passive Infrared (Motion) Sensor - Panasonic EKMB1201112
3. Ambient Light Sensor - Panasonic PNJ4K01F
4. Accelerometer/Absolute Orientation Sensor - Bosch BMX160
5. Environmental Sensor - Bosch BME680
6. MEMS Microphone - Knowles SPU0410LR5H

## Other components
* Macronix MX25R8035FZUIL0 SPI 8Mb NOR Flash chip
* Domain 1 Regulator - [LP5951MF-1.8](http://www.ti.com/lit/ds/symlink/lp5951.pdf)
* Domain 2 P-Channel Mosfet - [DMP3010LK3](https://www.diodes.com/assets/Datasheets/DMP3010LK3.pdf)

# Header Pins Usage

| Near Power Pads | Near MCU |
| --- | --- |
| 3V3 | GND |
| 3V3 | GND |
| - | - |
| - | - |
| - | I2C SDA |
| Pwr Domain1 EN (Flash nCS)  | I2C SCL |
| Light Analog | Flash MOSI |
| Mic Analog | Flash CLK |
| BMX INT 1 | Flash MISO |
| PIR Digital | Pwr Domain2 nEN |

# Power Domains

## Alway On
* PIR                           - 1uA
* Accelerometer (BMX160)        - 5uA in suspend
* Environmental Sensor (BME680) - 0.15uA in suspend

## Domain 1
Domain 1 is controlled by a 1.8V linear regulator. The Domain 1 enable signal toggles the regulator's active high enable pin.

* Ambient Light Sensor
* Microphone

## Domain 2
Domain 2 is controlled by a p-channel mosfet, thus the enable signal is active low.

* GridEye
* SPI Flash

# Protocols

| Sensor | Protocol |
| --- |--- |
| Flash | SPI |
| BMX160 | I2C, INT |
| BME680 | I2C |
| Light | Analog |
| Mic | Analog |
| PIR | Digital |
| GridEye | I2C |

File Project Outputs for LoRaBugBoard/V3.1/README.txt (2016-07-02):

Standard FR4 laminate
Thickness 0.062"
Drill sizes are actual tool sizes
Drill Tolerance +/- 0.008"
Adjust tools to free sizes where possible

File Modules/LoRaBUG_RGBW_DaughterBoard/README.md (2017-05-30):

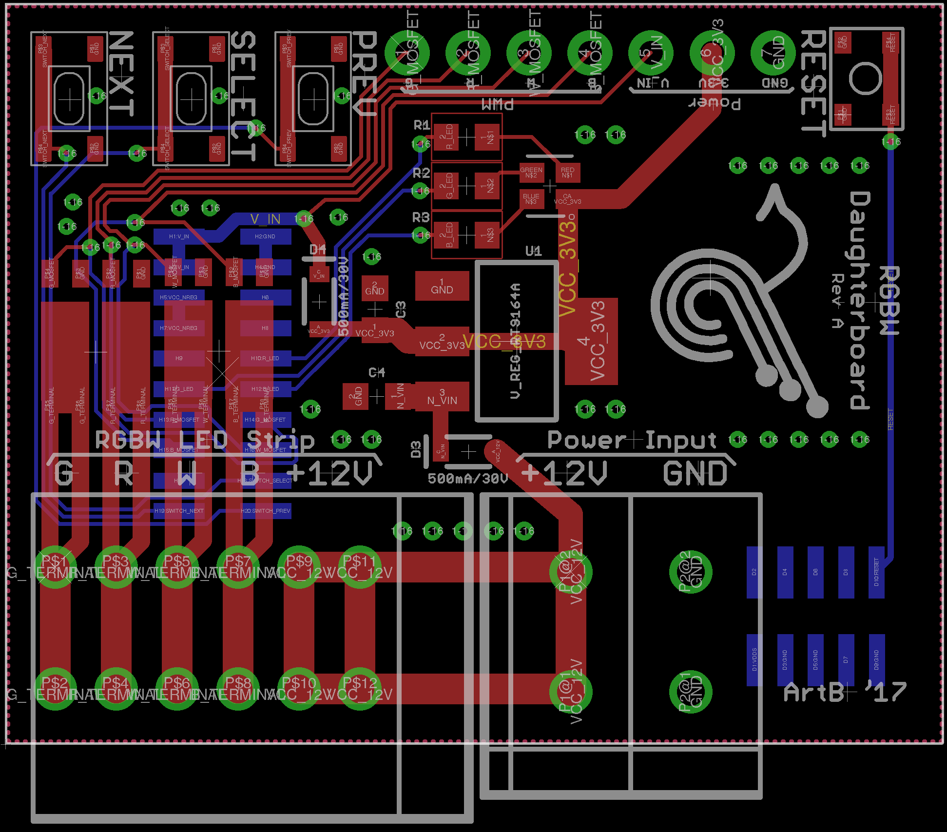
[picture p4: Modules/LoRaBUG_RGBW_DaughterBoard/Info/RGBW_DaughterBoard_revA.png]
RGBW_DaughterBoard_revA Picture


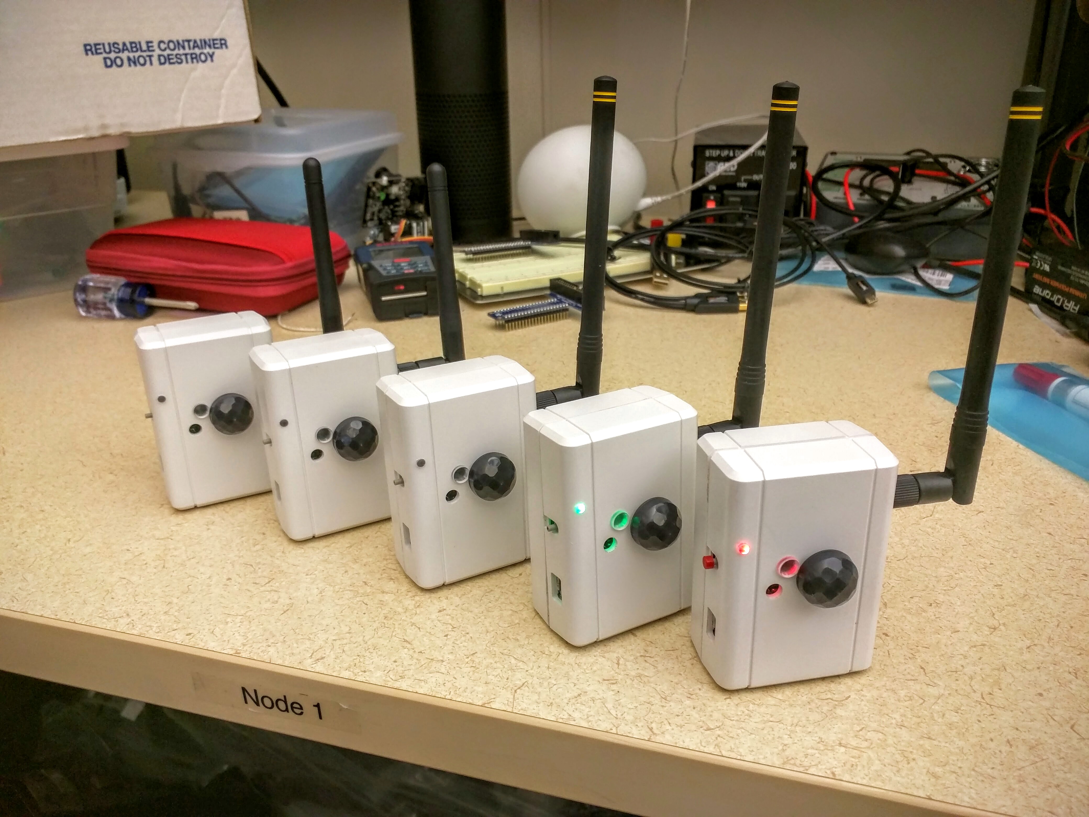
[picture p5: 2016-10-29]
Info/LoRaBugBoardV2_EnclosureEnvSensors.jpg

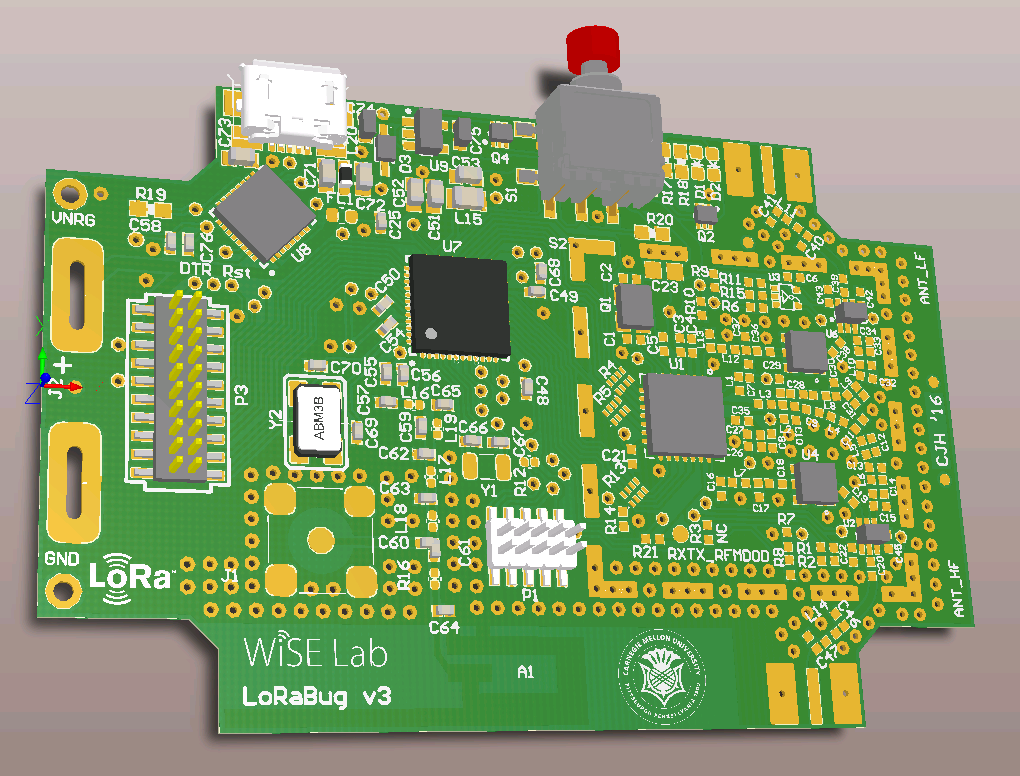
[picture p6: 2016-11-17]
Info/LoRaBugBoardV3_3D.png

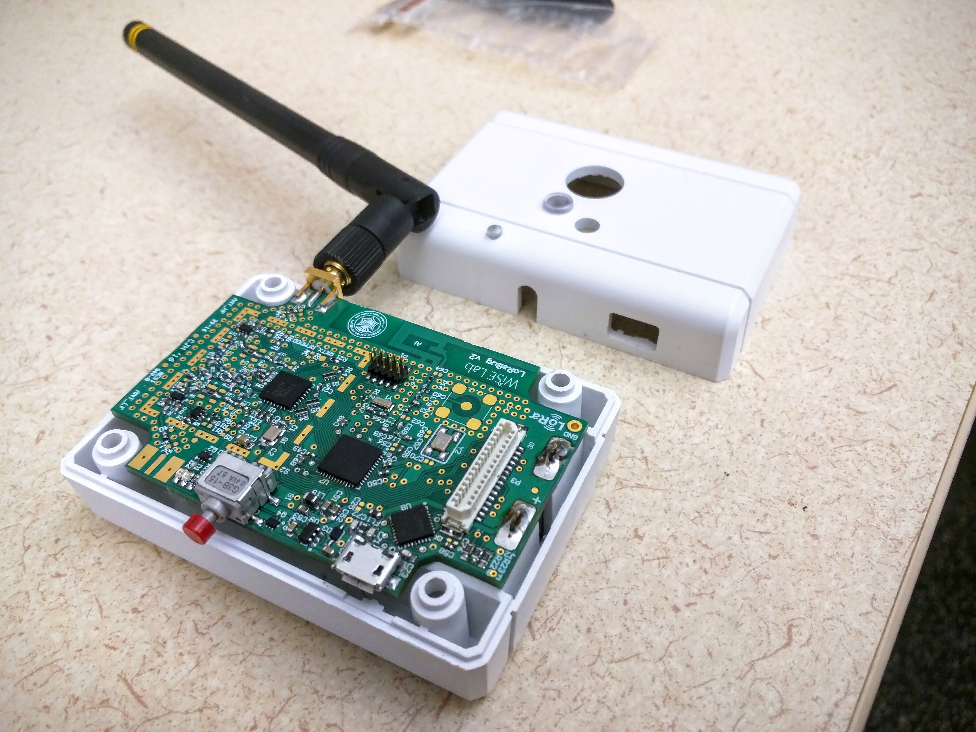
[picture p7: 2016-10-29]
Info/LoRaBugBoardV2_OpenEnclosure.jpg

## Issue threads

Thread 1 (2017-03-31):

Reset Button

ABalanuta, 2017-03-31:
New version should include a on-board reboot button.

linux4life798, 2017-03-31:
Is there some other reason why mapping the current button to driverlib/sys_ctrl.h's SysCtrlSystemReset() function doesn't suffice?

ABalanuta, 2017-03-31:
It is not a dedicated HW reset button, we should put a small one like the one on the launchpad near the leds.

linux4life798, 2017-03-31:
Yeah, but the Launchpad is a devkit.
You can also populate C76 and remove C58 to be able to hard reset via the FTDI DTR line.
The firefly doesn't have a reset.

linux4life798, 2017-04-01:
My apologies, didn't mean to close that. I was trying to cancel my comment draft. Let me give it more thought.

Closed 2020-11-13.

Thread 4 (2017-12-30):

868 MHz support

msadeghz, 2017-12-30:
Hi,
thanks for sharing the project knowledge, with details.
how can i find the L and C values for the RF part?

linux4life798, 2018-01-04:
Hi msadeghz,

That's a good question. In it's current configuration, the LoRaBug should be able to operate in the EU 868MHz band. They typically just group in the 868 and 915MHz bands together in the reference designs.
For testing in the 868MHz band, I would need to defer to some of the other OpenChirp EU members to comment on their experiences.

## Details
The LoRaBug follows the SX1276RF1JAS (JAS) reference design with some small tweaks.
The JAS reference design covers the 433 and 868/915MHz bands, whereas the competing EU reference design, SX1276RF1IAS (IAS), covers 169 and 868/915MHz bands.

With respect to the 868MHz band, the primary difference between the IAS (which is said to be `primarily targeted for ETSI/EU applications`) and the JAS, is that JAS design has the PA_BOOST configured to supply the 868/915MHz frequency range. This means the LoRaBug is theoretically capable of outputting +20dBm to 868/915MHz, compared to the +14dBm of the IAS ref design.

You can read about the differences between the reference designs in the [SX127x Reference Design Overview](http://www.semtech.com/images/datasheet/AN1200.19_SX127x_RefDesign_STD.pdf).

## Notes and References
* Some of the tweaks came from the SX1276MB1LAS reference design.
   - http://www.semtech.com/apps/filedown/down.php?file=SX1276MB1LAS_e311v02a_prod_folder.zip
   - https://os.mbed.com/components/SX1276MB1xAS/
* SX127x Docs & Resources tab on http://www.semtech.com/wireless-rf/rf-transceivers/sx1276/
* [SX127x Reference Design Overview](http://www.semtech.com/images/datasheet/AN1200.19_SX127x_RefDesign_STD.pdf)

Best,

Craig

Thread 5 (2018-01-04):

Switch to CC2640R2

linux4life798, 2018-01-04:
We should switch to the CC2640R2 (Bluetooth only) MCU/Transceiver, since 2.4GHz 802.15.4 doesn't seem necessary and it would buy us more flash space.

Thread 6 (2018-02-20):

Q1 pin swap - programming and stuck on reset problems

anhluong, 2018-02-20:

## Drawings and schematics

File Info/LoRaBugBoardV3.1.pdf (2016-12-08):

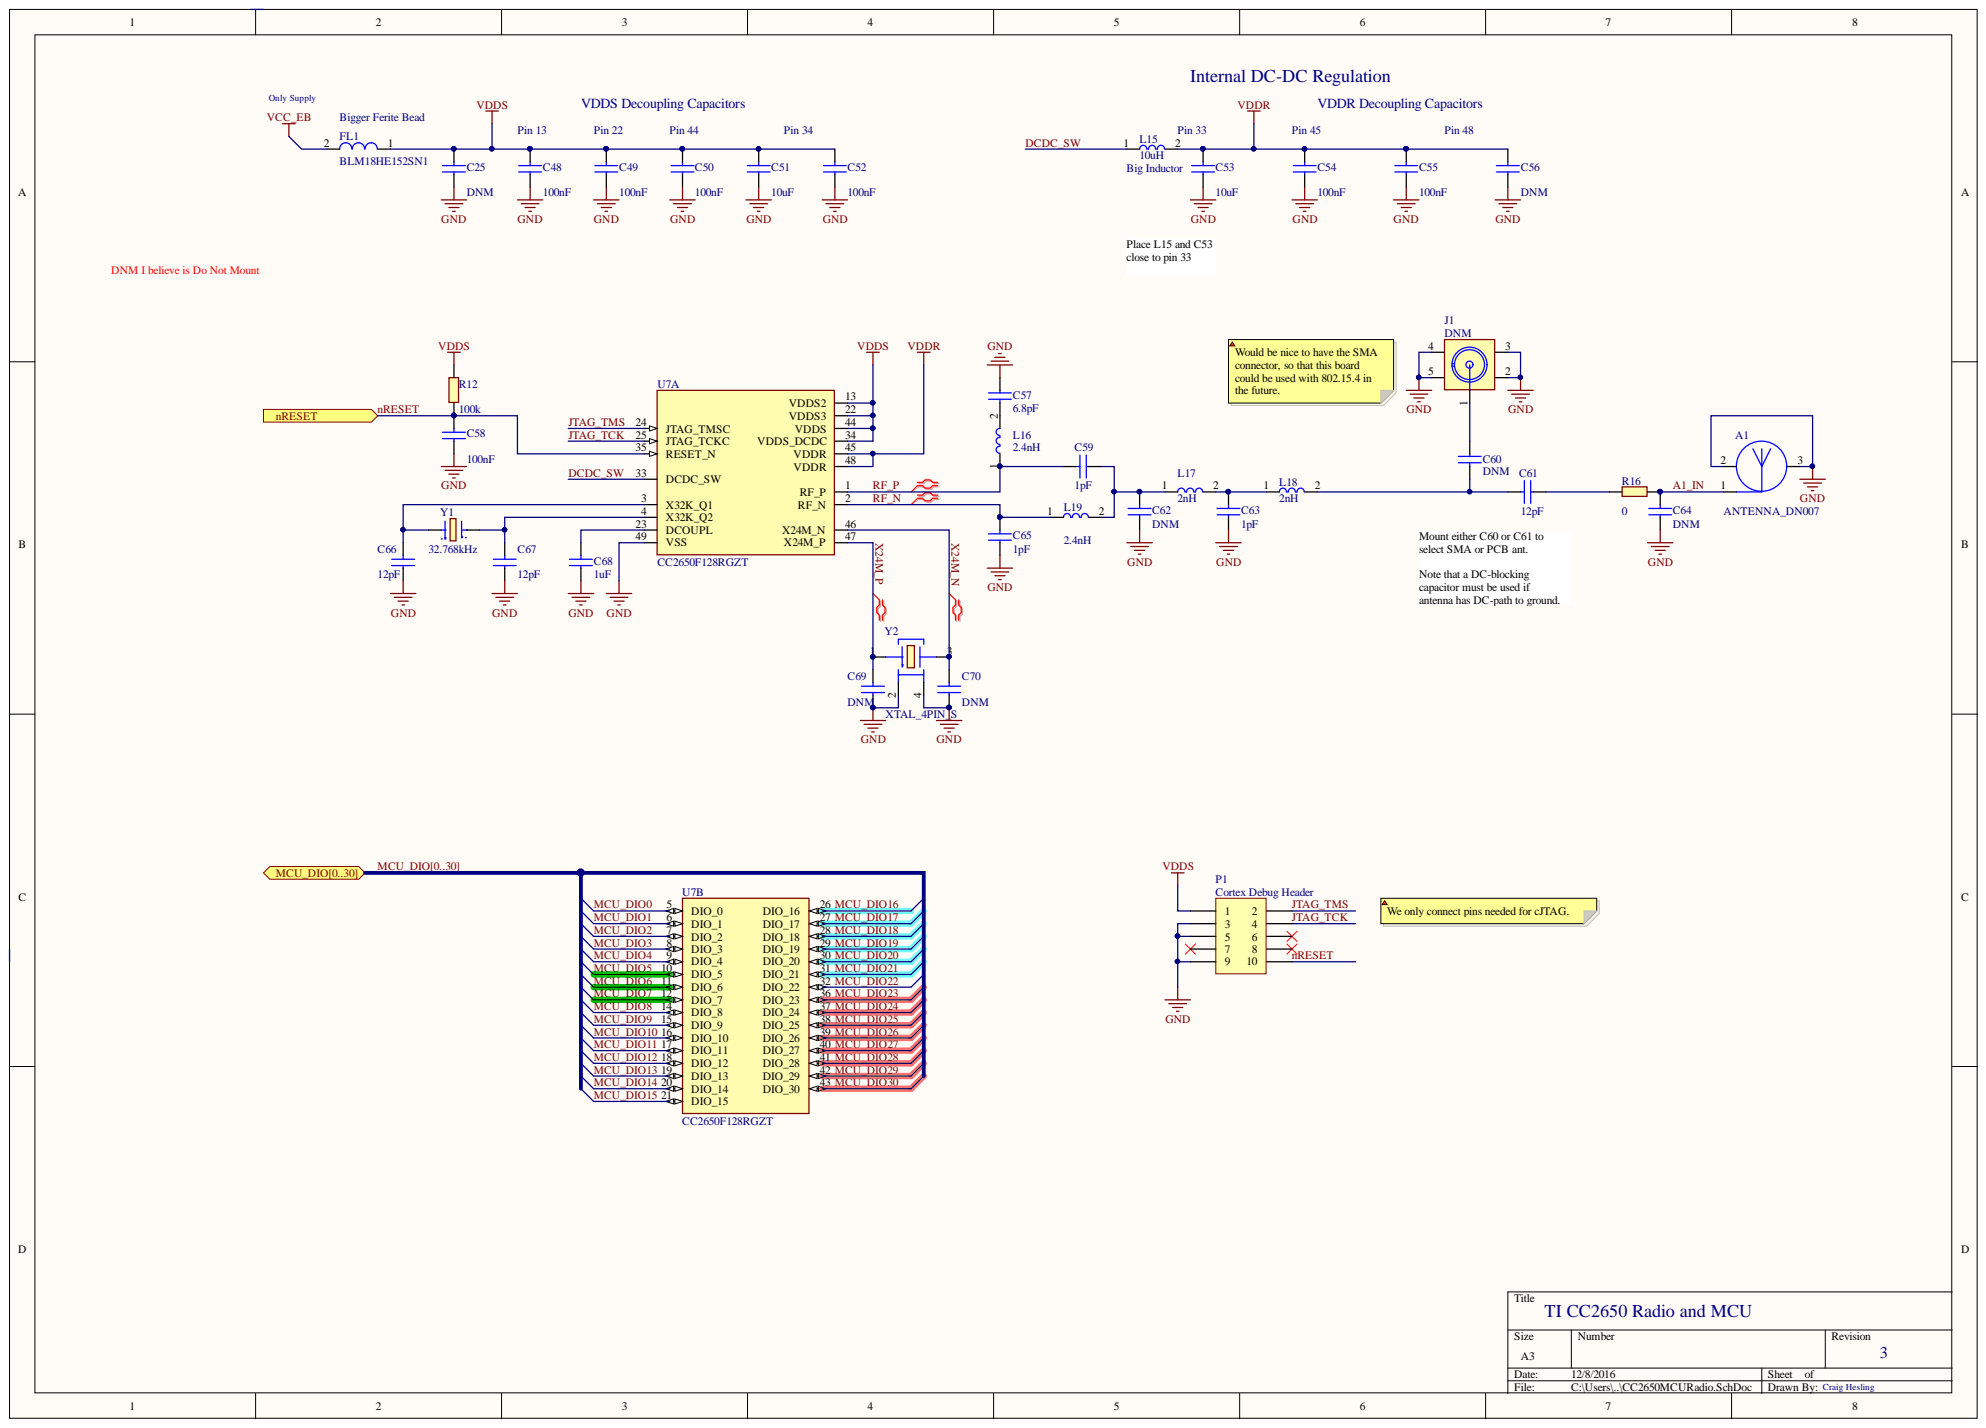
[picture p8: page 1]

Internal DC-DC Regulation

DNM I believe is Do Not Mount

Would be nice to have the SMA
connector, so that this board
could be used with 802.15.4 in
the future.

Mount either C60 or C61 to
select SMA or PCB ant.

Note that a DC-blocking
capacitor must be used if
antenna has DC-path to ground.

We only connect pins needed for cJTAG.

Title
TI CC2650 Radio and MCU

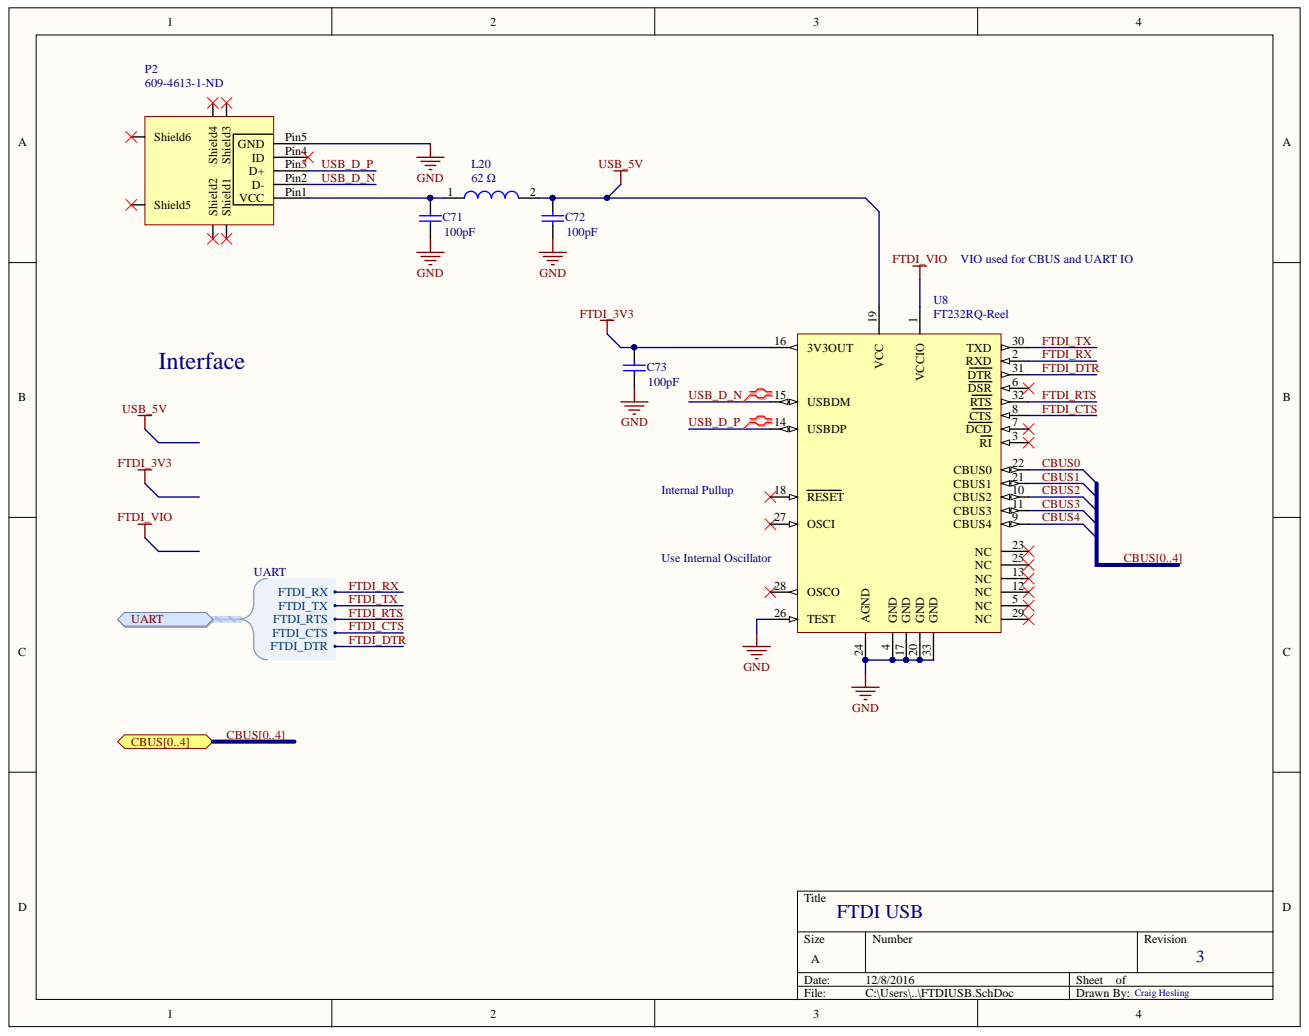
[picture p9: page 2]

FTDI_VIO VIO used for CBUS and UART IO

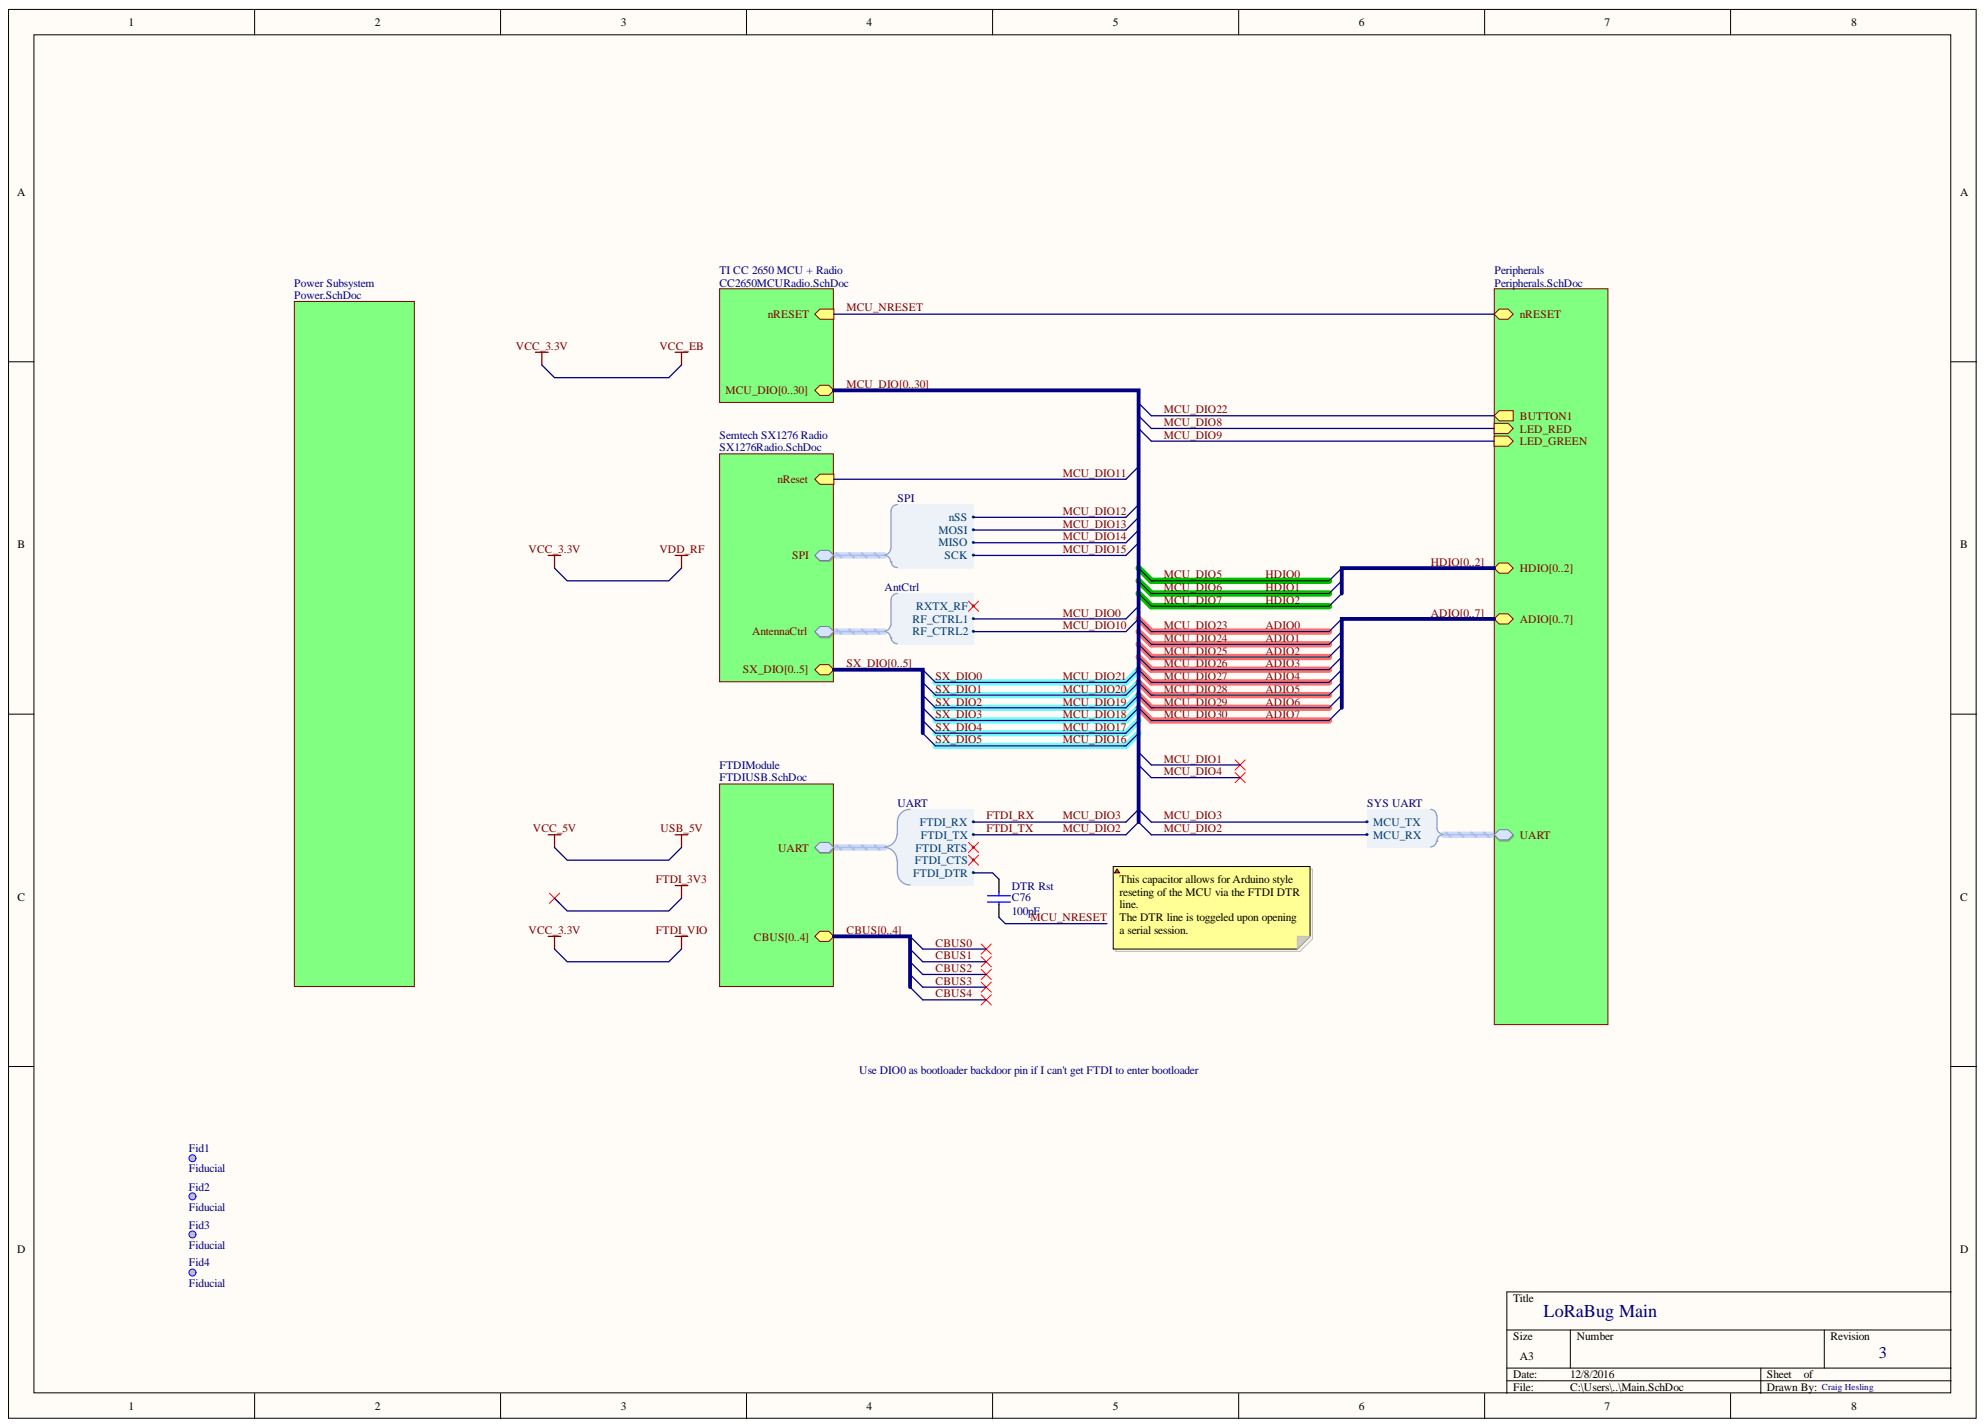
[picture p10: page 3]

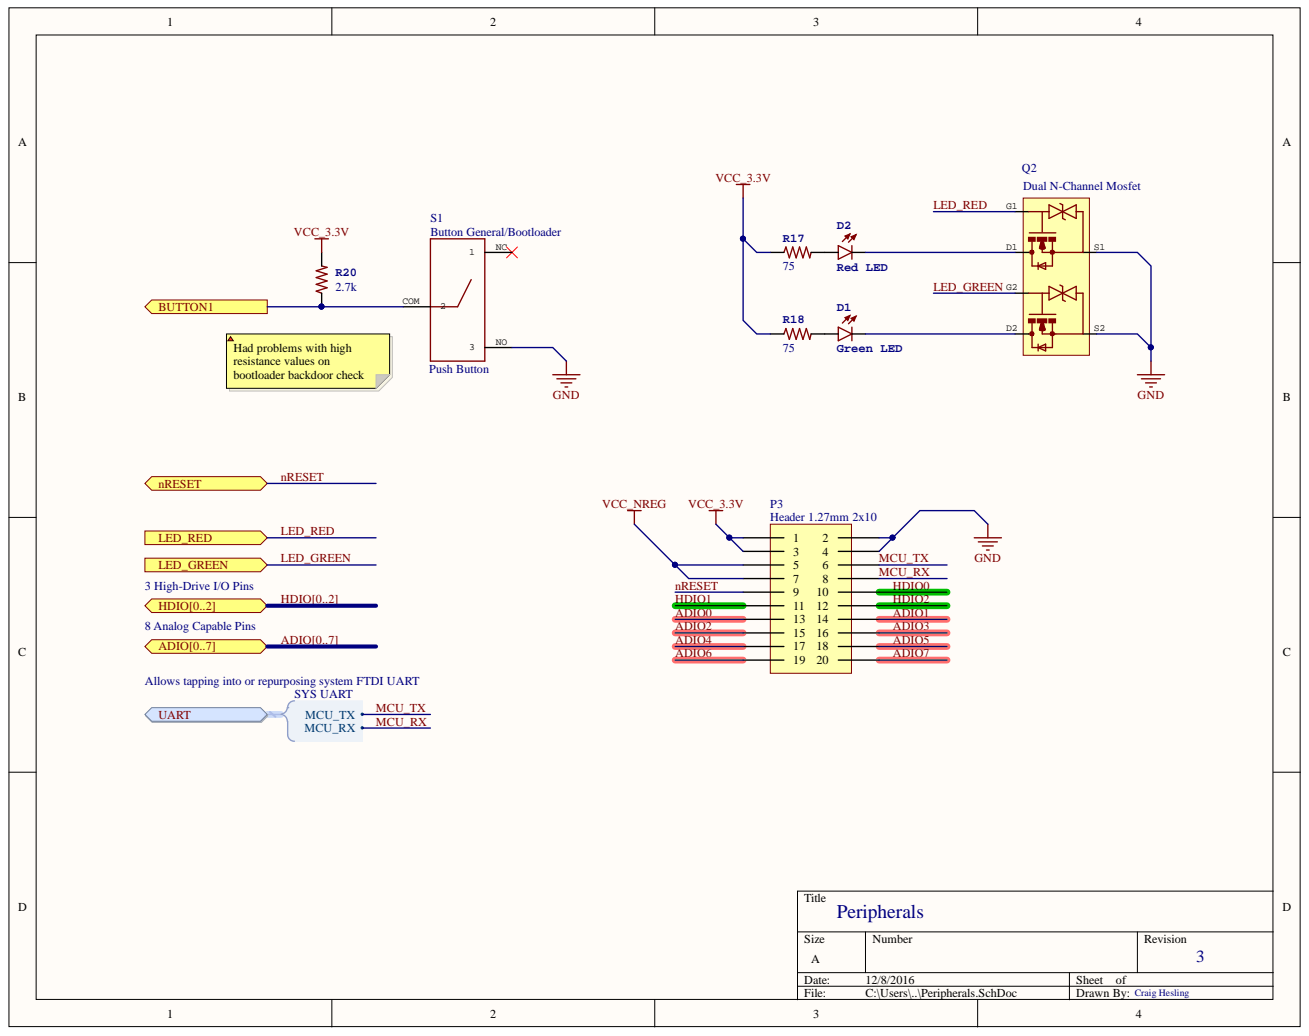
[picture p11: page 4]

Had problems with high
resistance values on
bootloader backdoor check

Allows tapping into or repurposing system FTDI UART

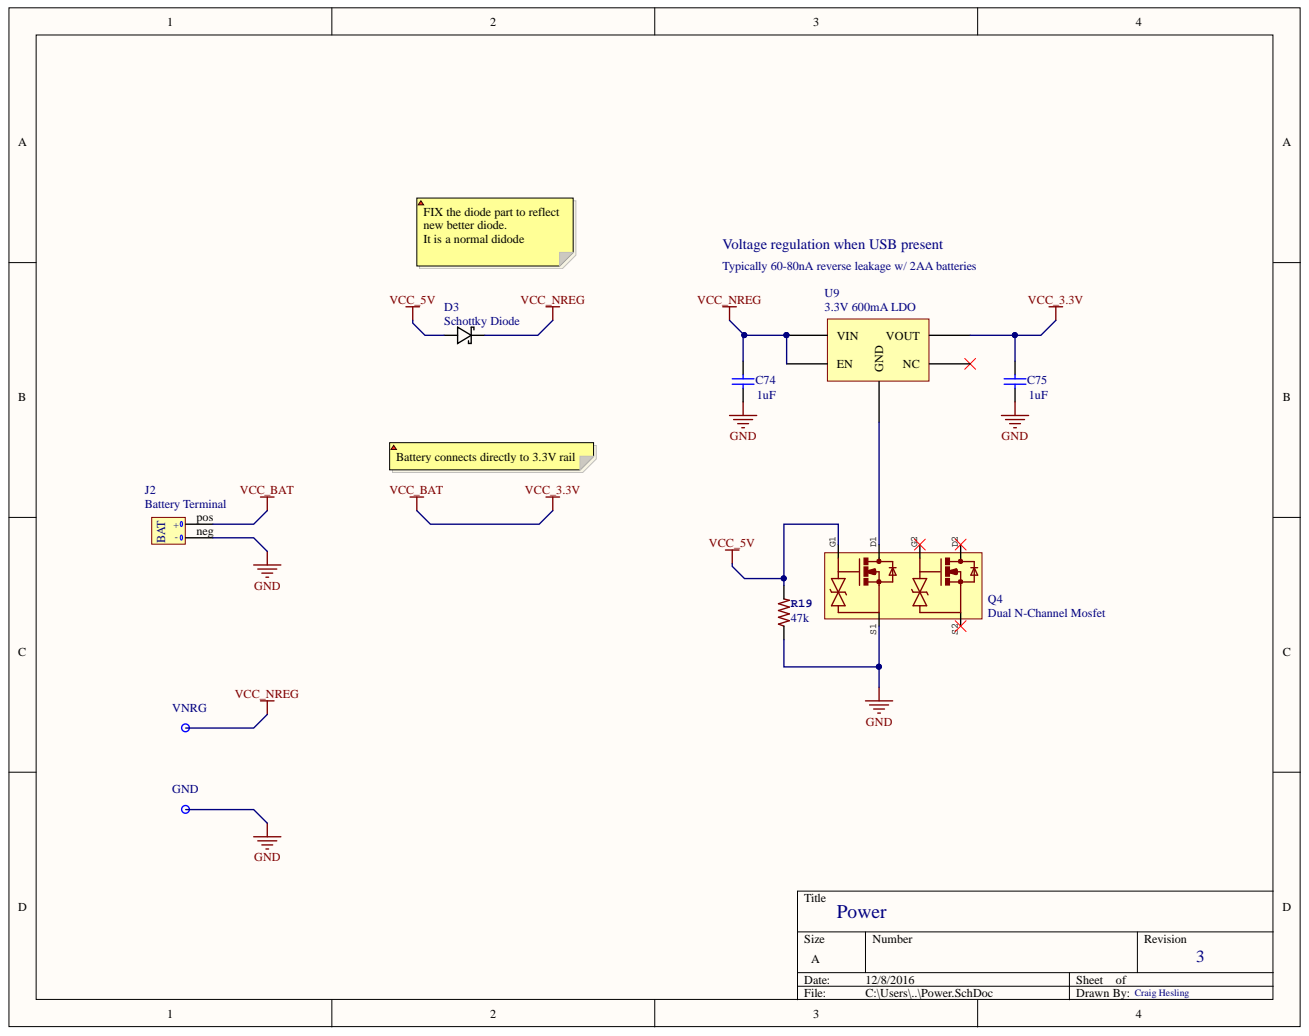
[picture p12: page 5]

Voltage regulation when USB present

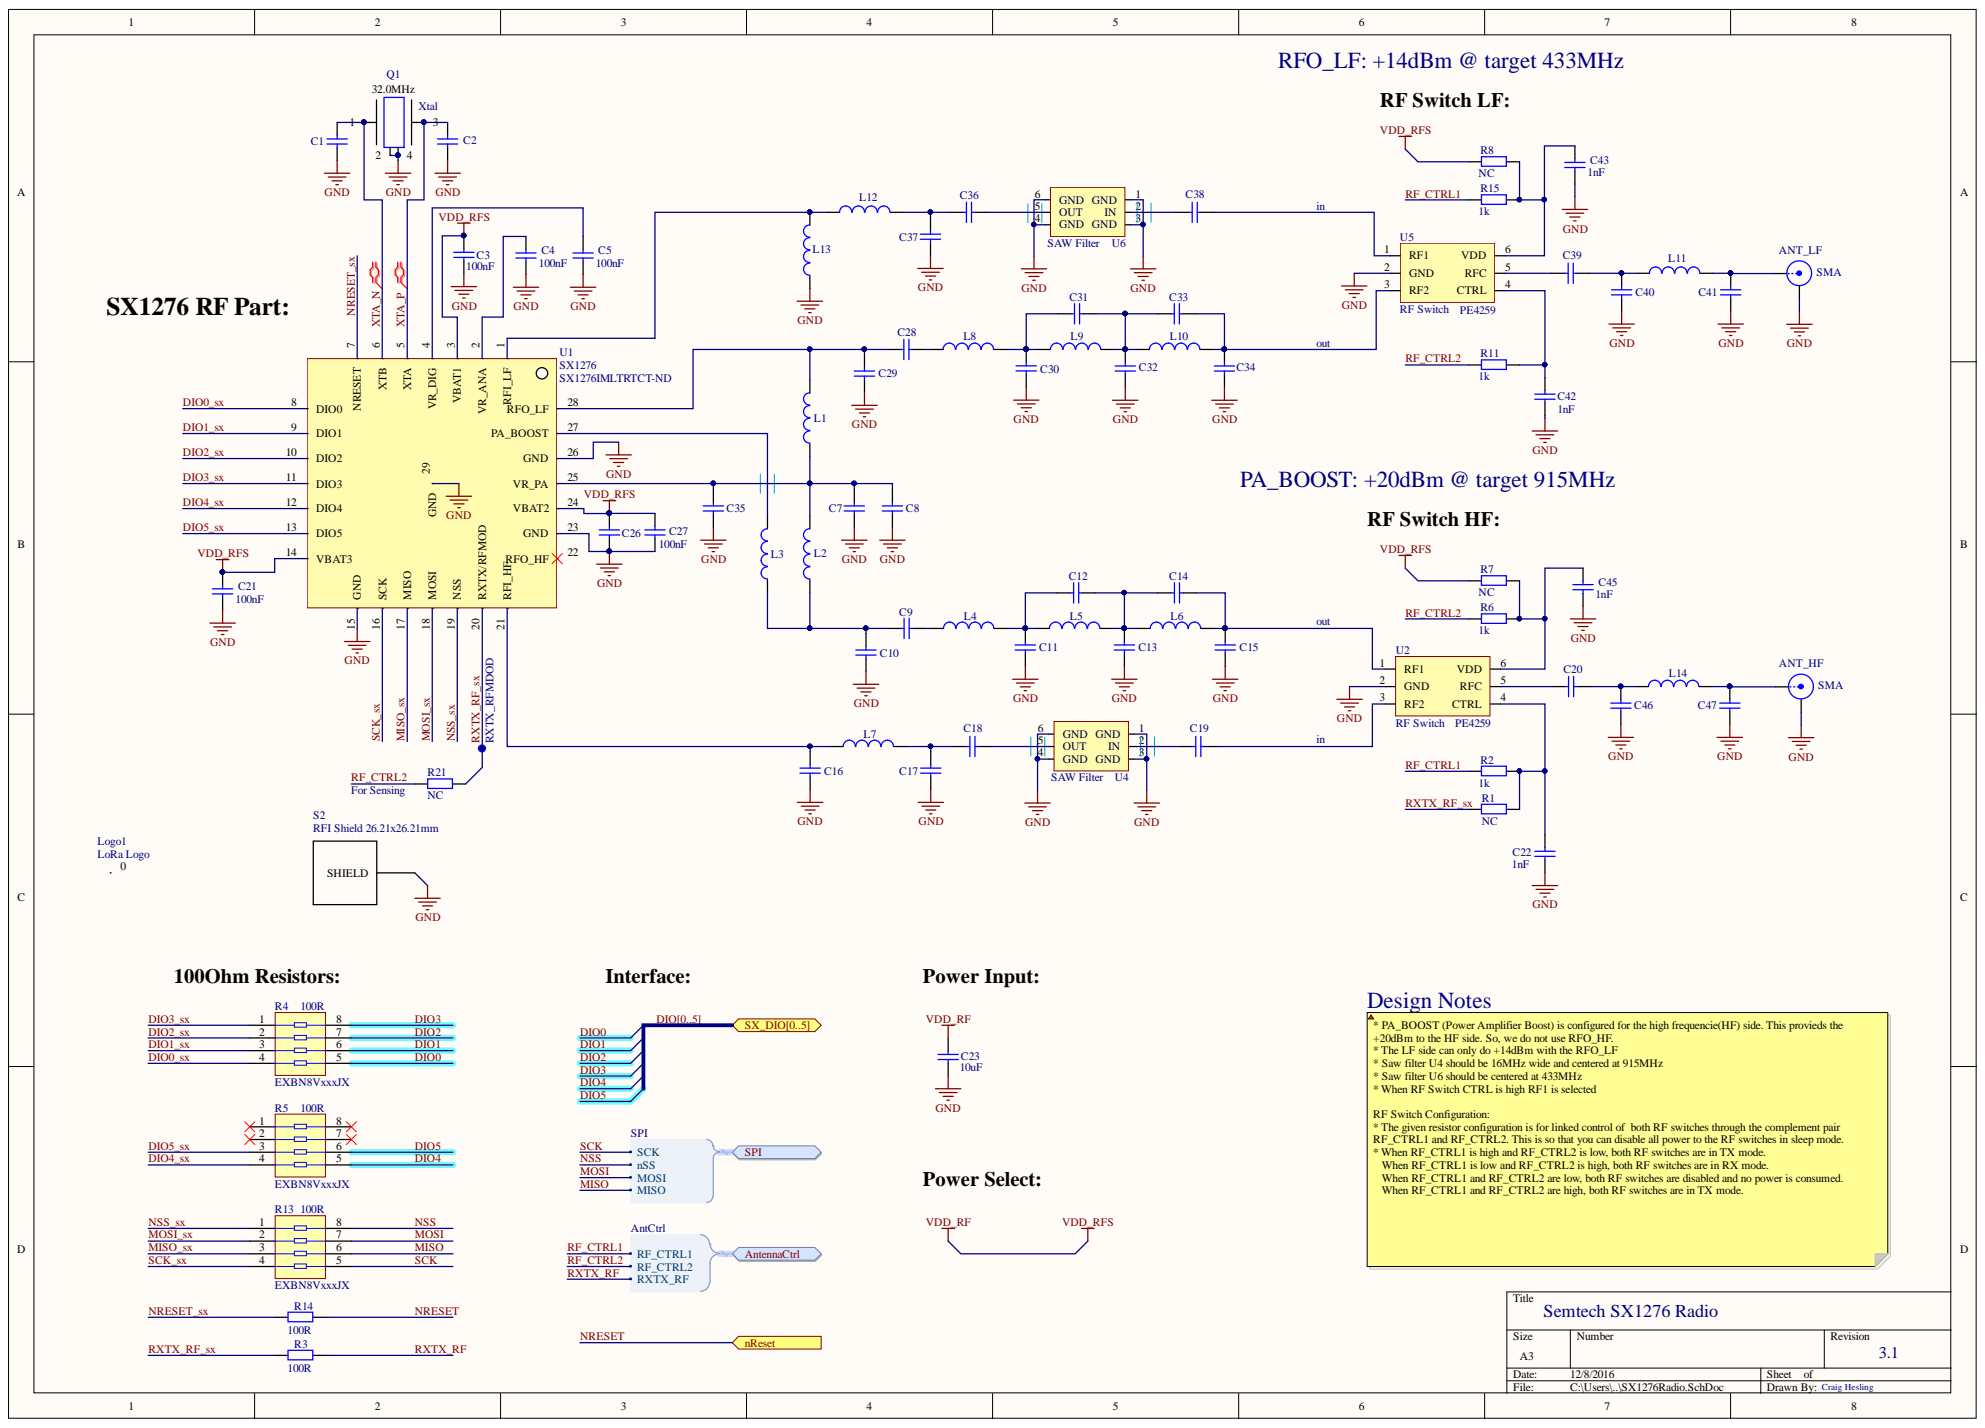
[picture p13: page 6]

* PA_BOOST (Power Amplifier Boost) is configured for the high frequencie(HF) side. This provieds the
+20dBm to the HF side. So, we do not use RFO_HF.
* The LF side can only do +14dBm with the RFO_LF
* Saw filter U4 should be 16MHz wide and centered at 915MHz
* Saw filter U6 should be centered at 433MHz
* When RF Switch CTRL is high RF1 is selected

RF Switch Configuration:
* The given resistor configuration is for linked control of both RF switches through the complement pair
RF_CTRL1 and RF_CTRL2. This is so that you can disable all power to the RF switches in sleep mode.
* When RF_CTRL1 is high and RF_CTRL2 is low, both RF switches are in TX mode.
When RF_CTRL1 is low and RF_CTRL2 is high, both RF switches are in RX mode.
When RF_CTRL1 and RF_CTRL2 are low, both RF switches are disabled and no power is consumed.
When RF_CTRL1 and RF_CTRL2 are high, both RF switches are in TX mode.

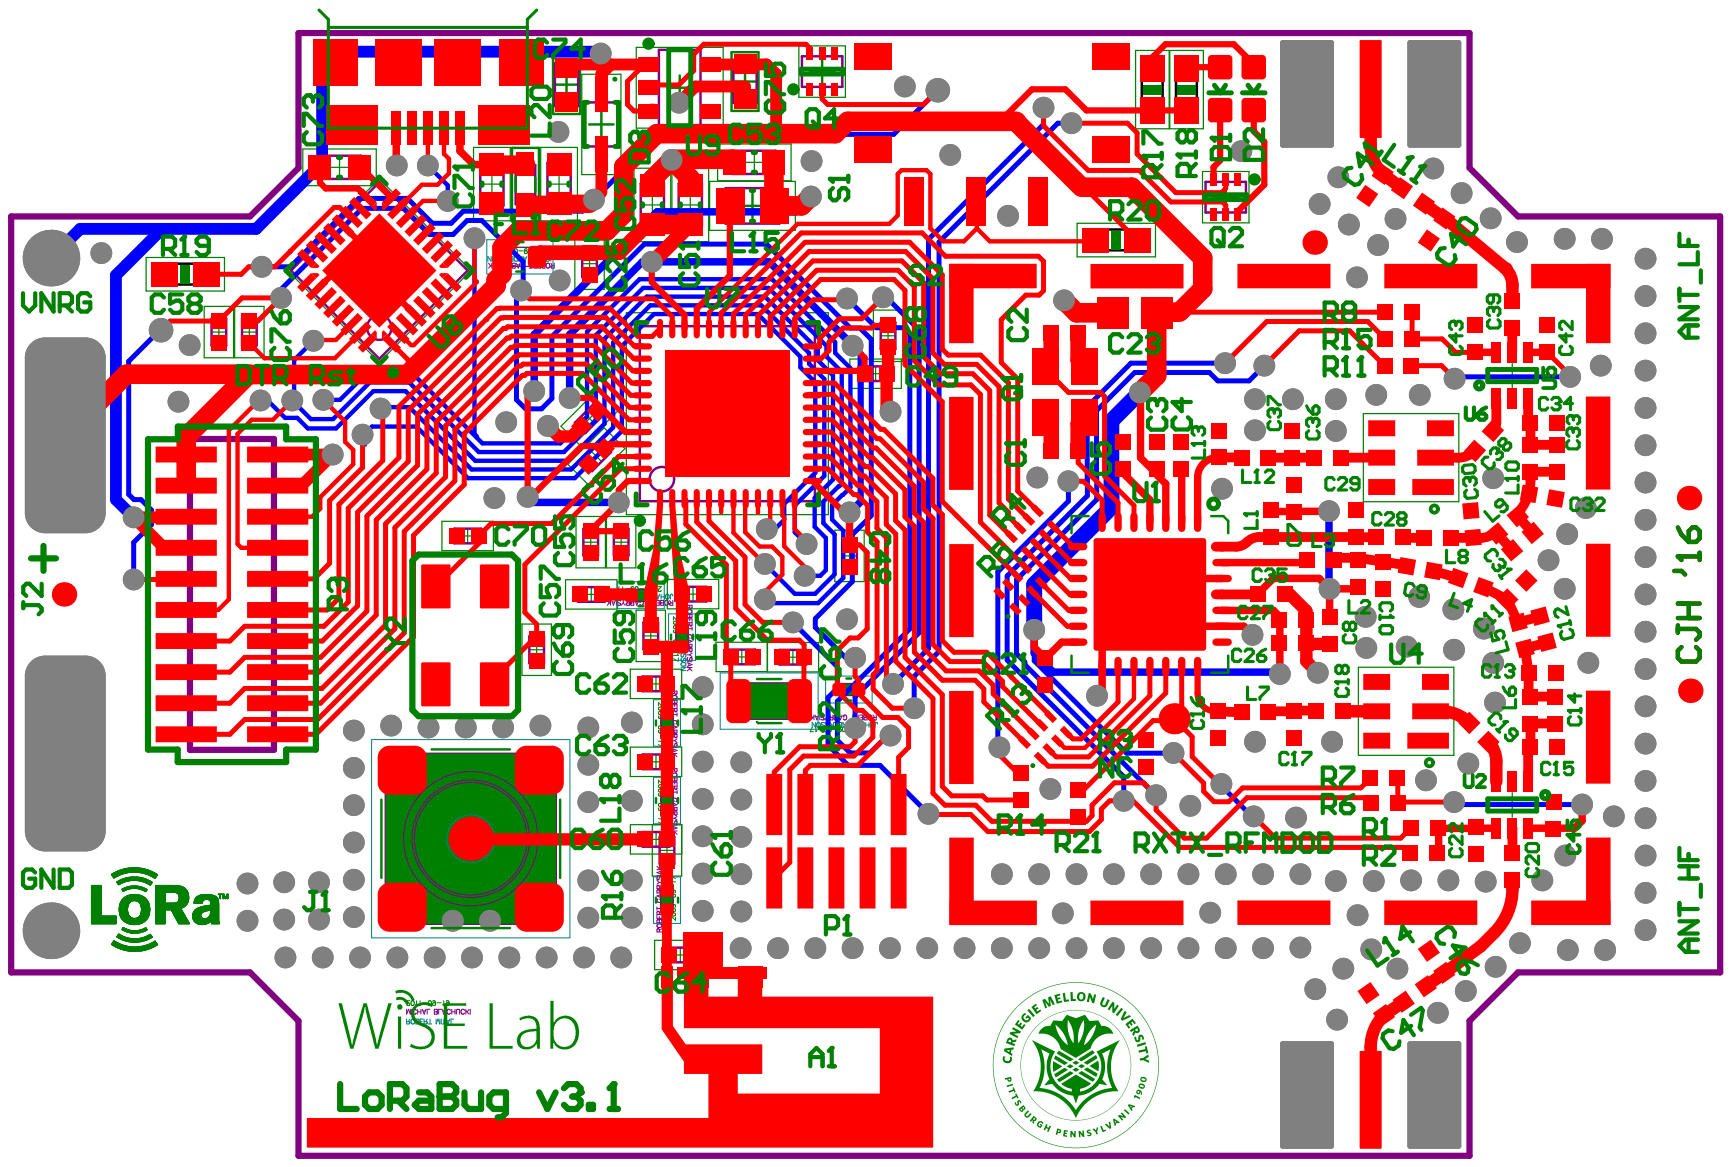
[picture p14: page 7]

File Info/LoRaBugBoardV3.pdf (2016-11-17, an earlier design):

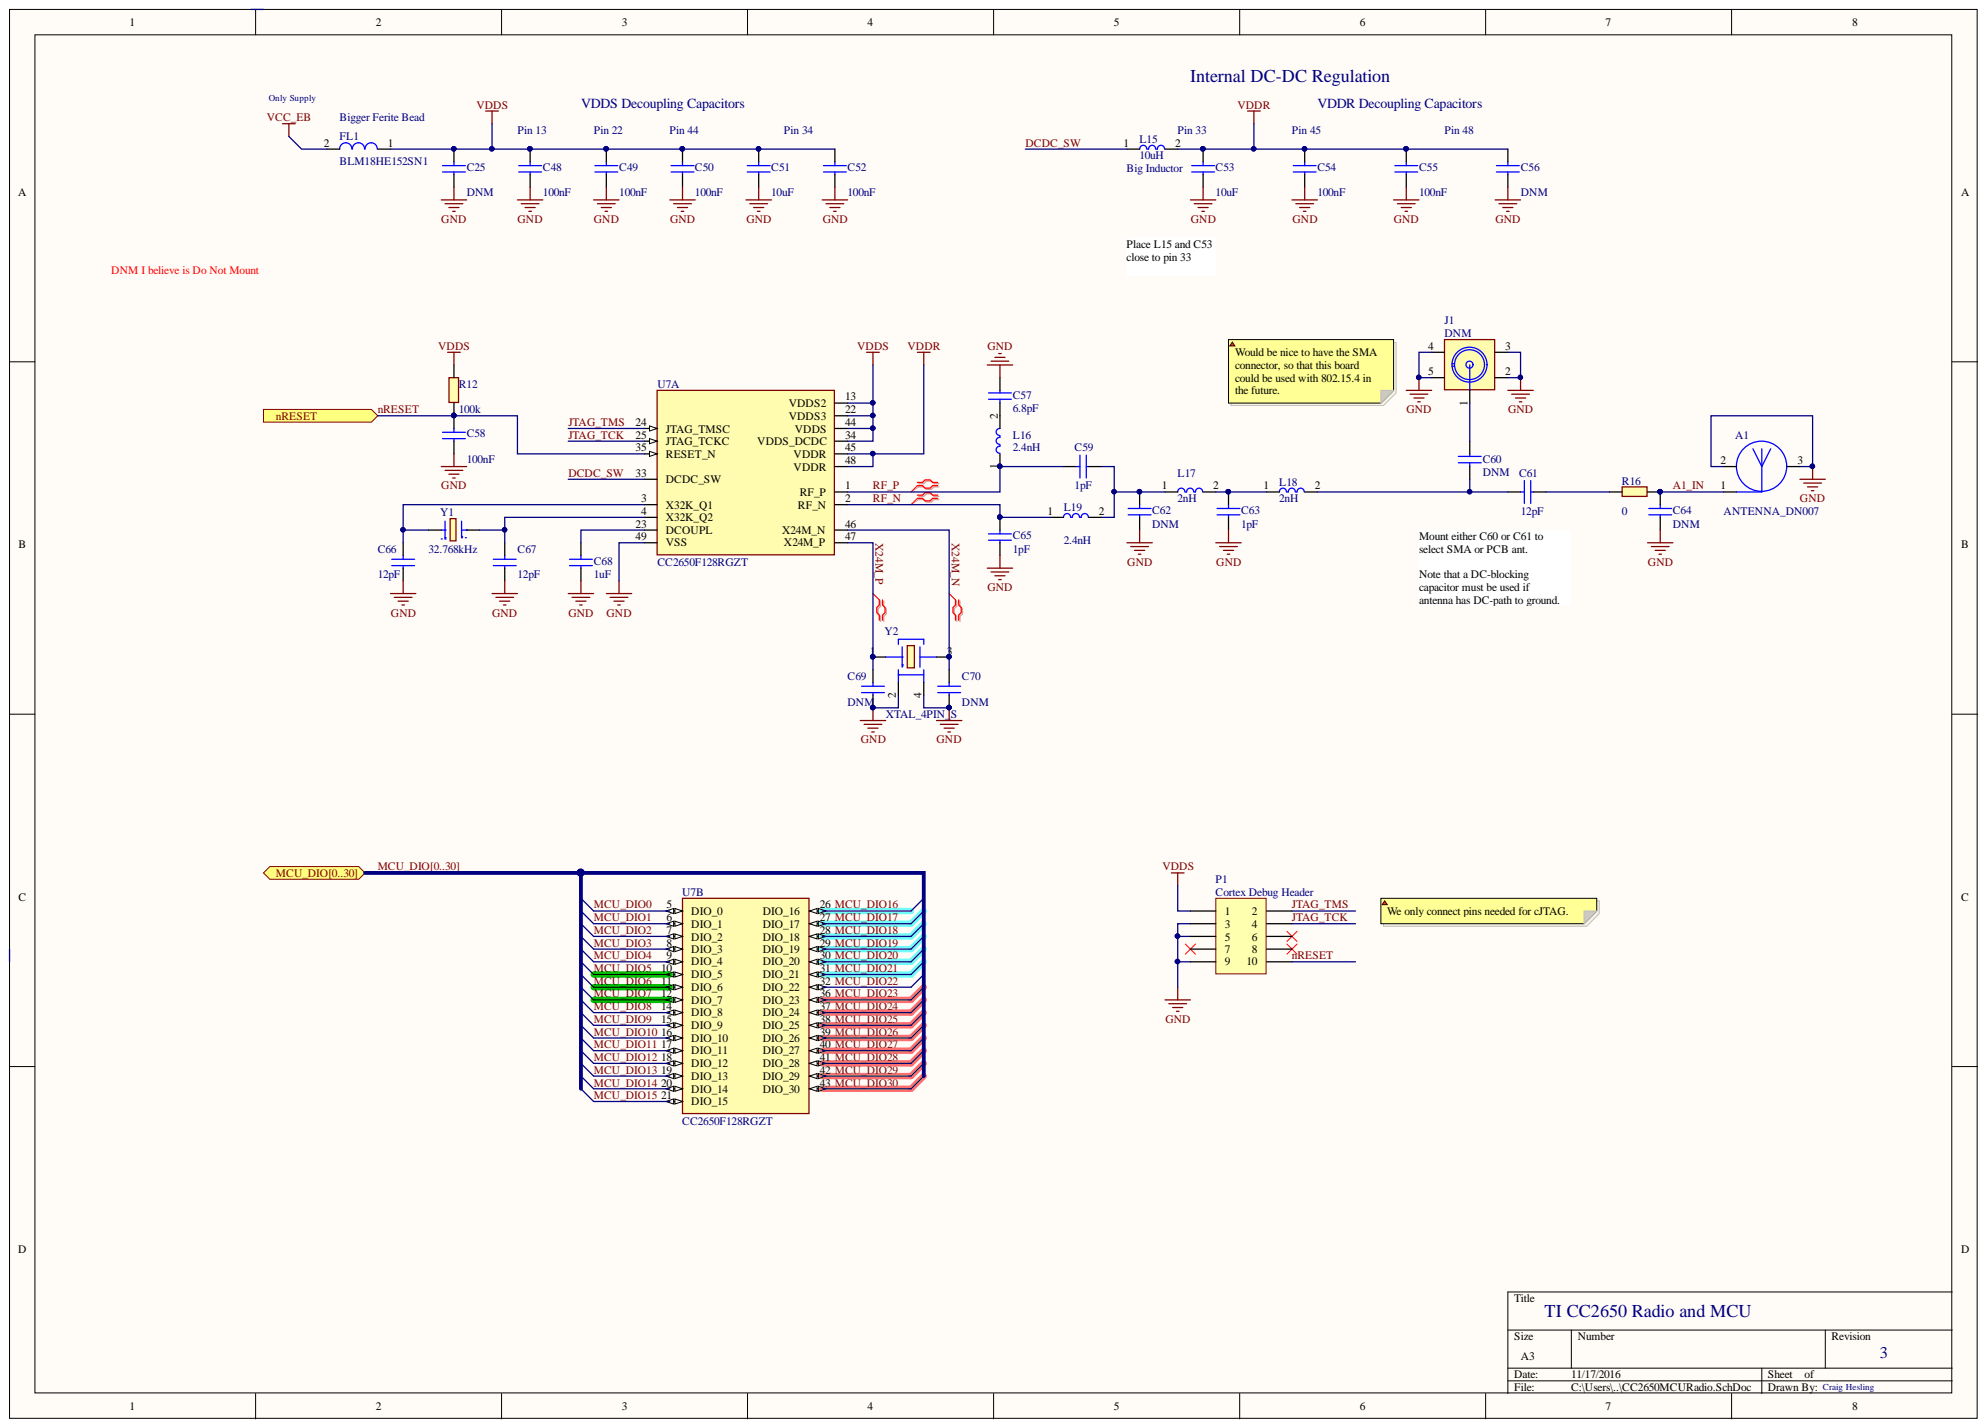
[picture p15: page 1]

Internal DC-DC Regulation

DNM I believe is Do Not Mount

Would be nice to have the SMA
connector, so that this board
could be used with 802.15.4 in
the future.

Mount either C60 or C61 to
select SMA or PCB ant.

Note that a DC-blocking
capacitor must be used if
antenna has DC-path to ground.

We only connect pins needed for cJTAG.

Title
TI CC2650 Radio and MCU

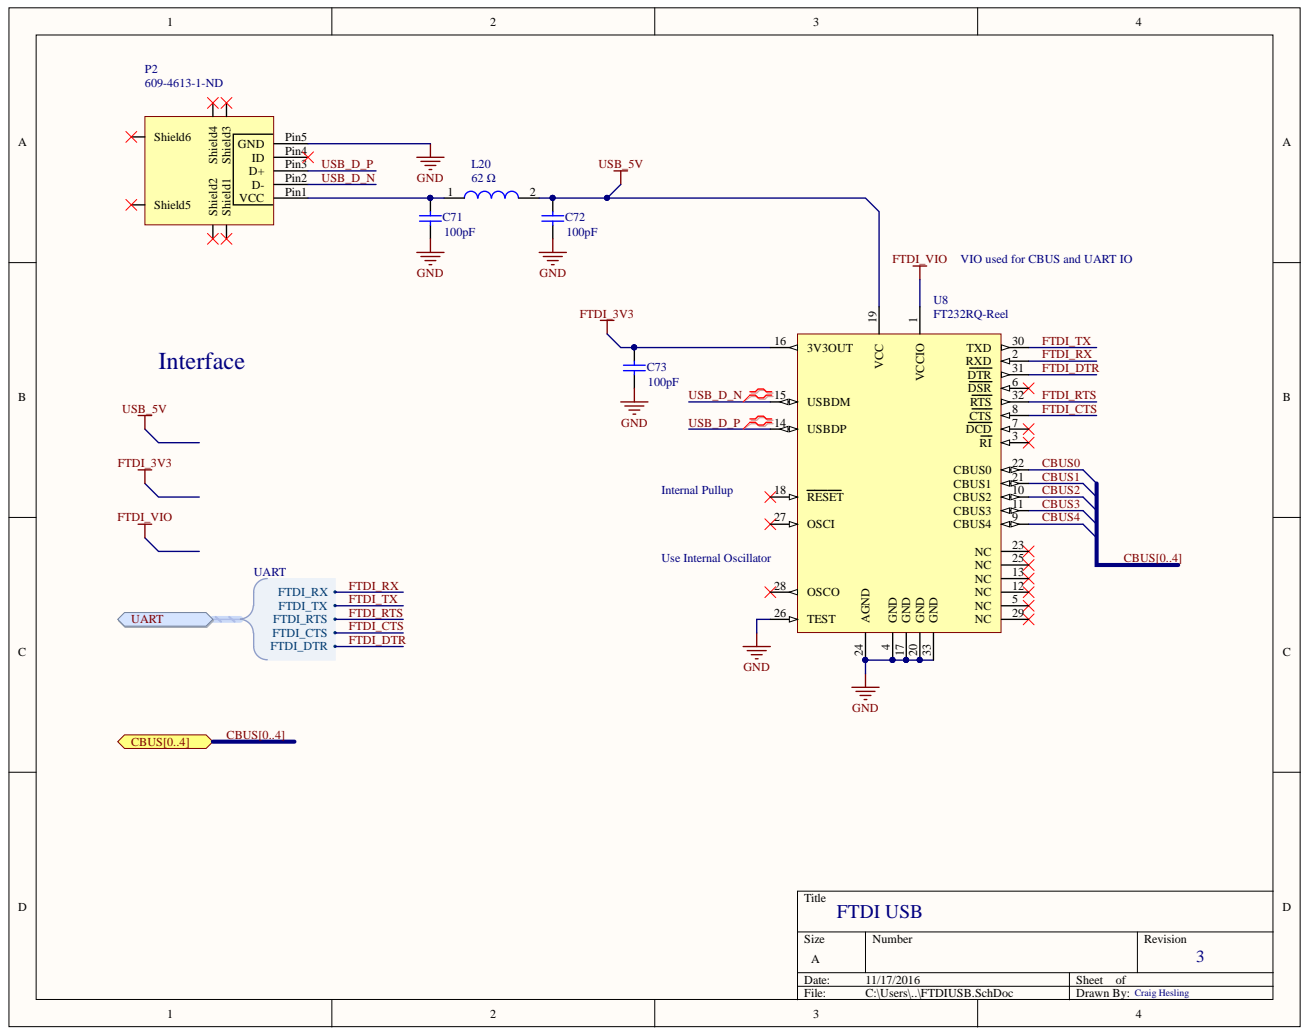
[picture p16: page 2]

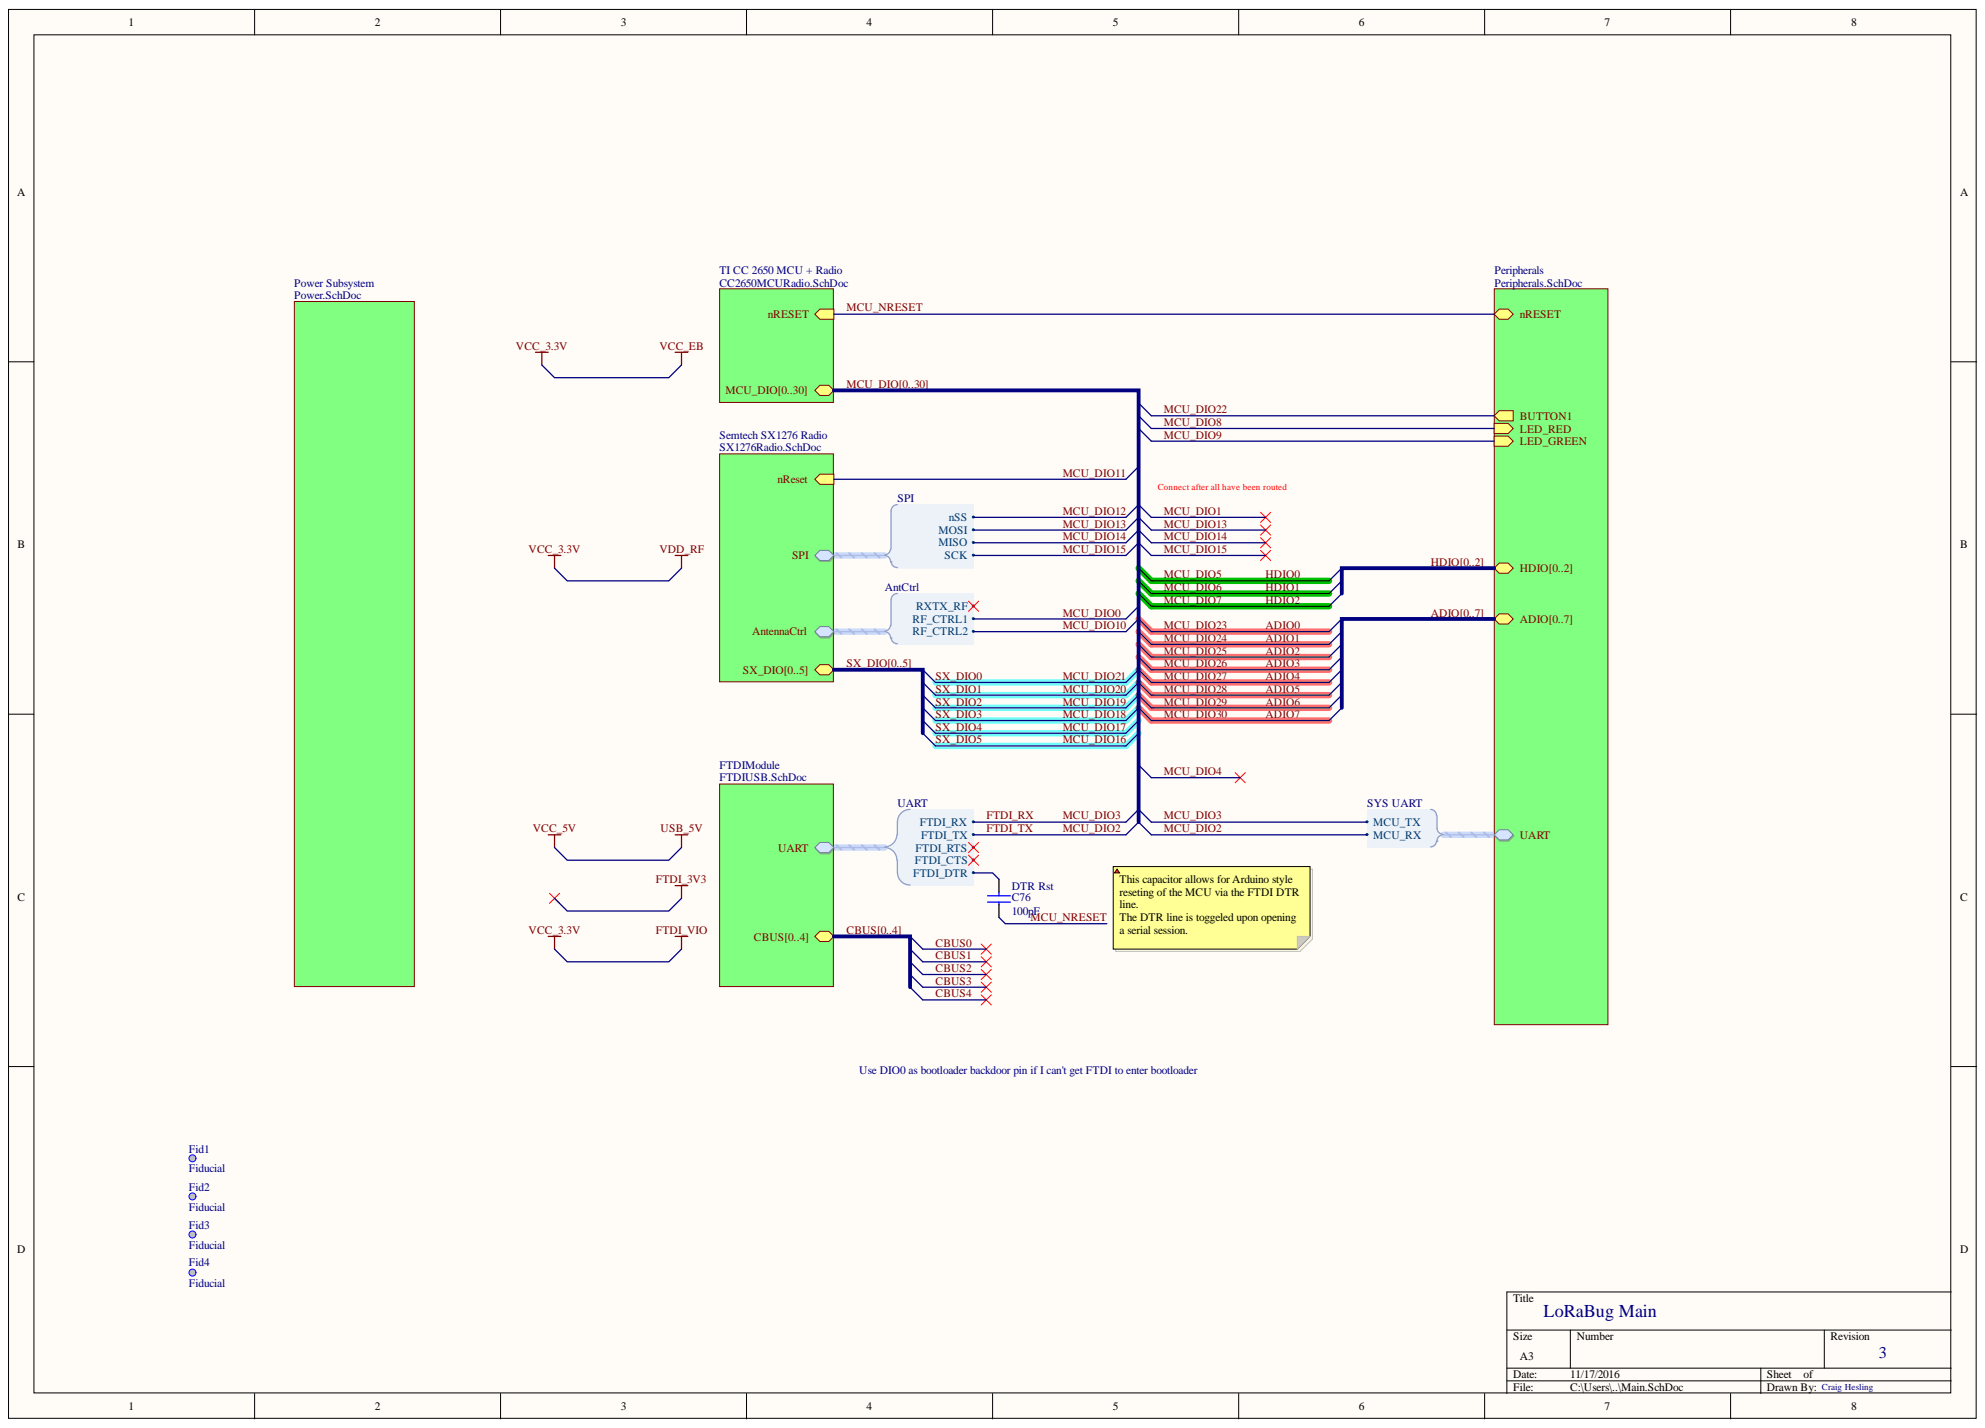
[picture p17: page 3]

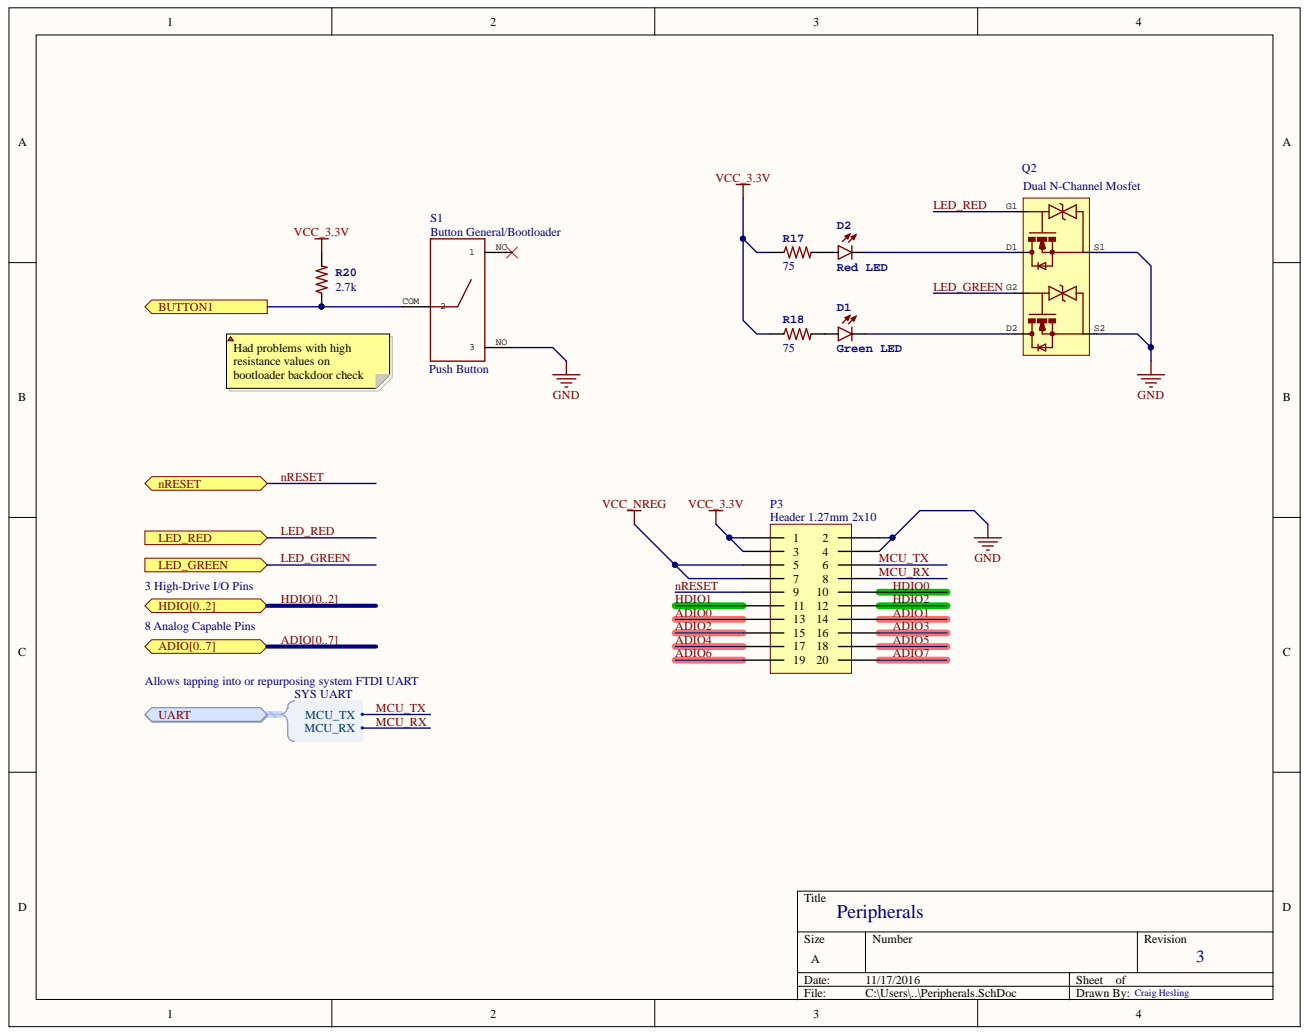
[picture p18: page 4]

Had problems with high
resistance values on
bootloader backdoor check

Allows tapping into or repurposing system FTDI UART

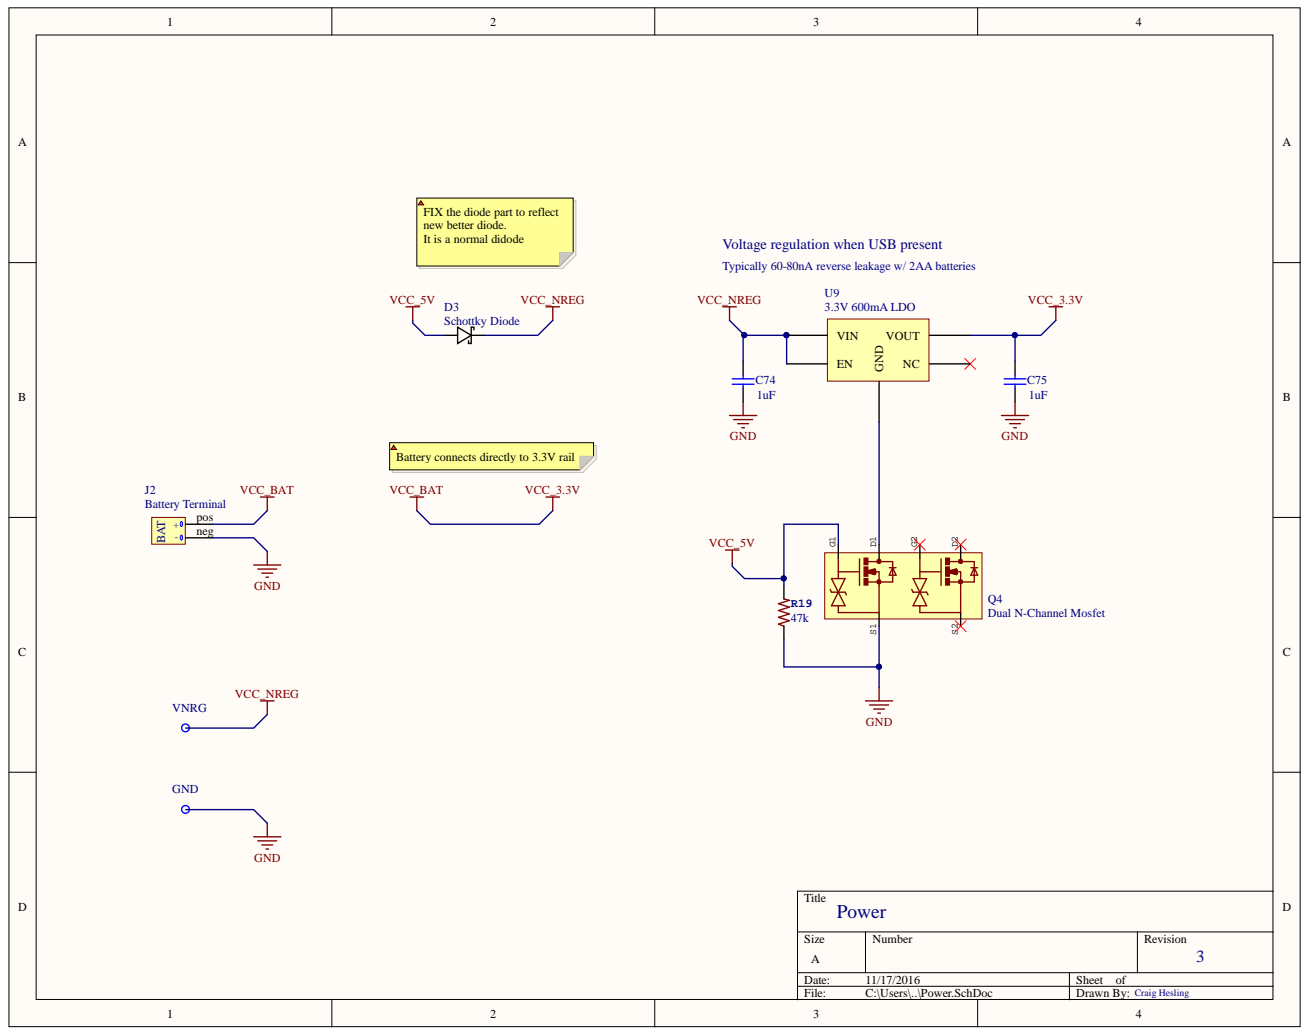
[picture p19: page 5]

Voltage regulation when USB present


* PA_BOOST (Power Amplifier Boost) is configured for the high frequencie(HF) side. This provieds the
+20dBm to the HF side. So, we do not use RFO_HF.
* The LF side can only do +14dBm with the RFO_LF
* Saw filter U4 should be 16MHz wide and centered at 915MHz
* Saw filter U6 should be centered at 433MHz
* When RF Switch CTRL is high RF1 is selected

RF Switch Configuration:
* The given resistor configuration is for linked control of both RF switched through RF_CTRL1.
This is to mimic the controls of the Semtech mbed board.
RF_CTRL2 is connected to the SX's RXTX_RF to get feedback from the SX.
When RF_CTRL1 is high, both are in TX mode.


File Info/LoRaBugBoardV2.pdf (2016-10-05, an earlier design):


Internal DC-DC Regulation

DNM I believe is Do Not Mount

Would be nice to have the SMA
connector, so that this board
could be used with 802.15.4 in
the future.

Mount either C60 or C61 to
select SMA or PCB ant.

Note that a DC-blocking
capacitor must be used if
antenna has DC-path to ground.

Title
TI CC2650 Radio and MCU


FTDI_VIO VIO used for CBUS and UART IO


TI CC 2650 MCU + Radio
CC2650MCURadio.SchDoc

Connect after all have been routed

Voltage regulation when USB present

FTDI_TX
FTDI_RX

Use DIO0 as bootloader backdoor pin if I can't get FTDI to enter bootloader


Pink wires denote pins that are
connected/used on the environemnt sensor
board.

TI CC2650 doesn't have a dedicated AREF. It uses an
internal 4.3V ref OR VDDS.
We will input AREF as the last Analog pin for internal
comparison.


* PA_BOOST (Power Amplifier Boost) is configured for the high frequencie(HF) side. This provieds the
+20dBm to the HF side. So, we do not use RFO_HF.
* The LF side can only do +14dBm with the RFO_LF
* Saw filter U4 should be 16MHz wide and centered at 915MHz
* Saw filter U6 should be centered at 433MHz
* When RF Switch CTRL is high RF1 is selected

RF Switch Configuration:
* The given resistor configuration is for linked control of both RF switched through RF_CTRL1.
This is to mimic the controls of the Semtech mbed board.
RF_CTRL2 is connected to the SX's RXTX_RF to get feedback from the SX.
When RF_CTRL1 is high, both are in TX mode.


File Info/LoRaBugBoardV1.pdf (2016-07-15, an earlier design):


Internal DC-DC Regulation

DNM I believe is Do Not Mount

Would be nice to have the SMA
connector, so that this board
could be used with 802.15.4 in
the future.

Mount either C60 or C61 to
select SMA or PCB ant.

Note that a DC-blocking
capacitor must be used if
antenna has DC-path to ground.

Title
TI CC2650 Radio and MCU


TODO: Connect USB Shielding

FTDI_VIO VIO used for CBUS and UART IO



log pin for int


* PA_BOOST (Power Amplifier Boost) is configured for the high frequencie(HF) side. This provieds the
+20dBm to the HF side. So, we do not use RFO_HF.
* The LF side can only do +14dBm with the RFO_LF
* Saw filter U4 should be 16MHz wide and centered at 915MHz
* Saw filter U6 should be centered at 433MHz
* When RF Switch CTRL is high RF1 is selected

RF Switch Configuration:
* The given resistor configuration is for linked control of both RF switched through RF_CTRL1.
This is to mimic the controls of the Semtech mbed board.
RF_CTRL2 is connected to the SX's RXTX_RF to get feedback from the SX.
When RF_CTRL1 is high, both are in TX mode.


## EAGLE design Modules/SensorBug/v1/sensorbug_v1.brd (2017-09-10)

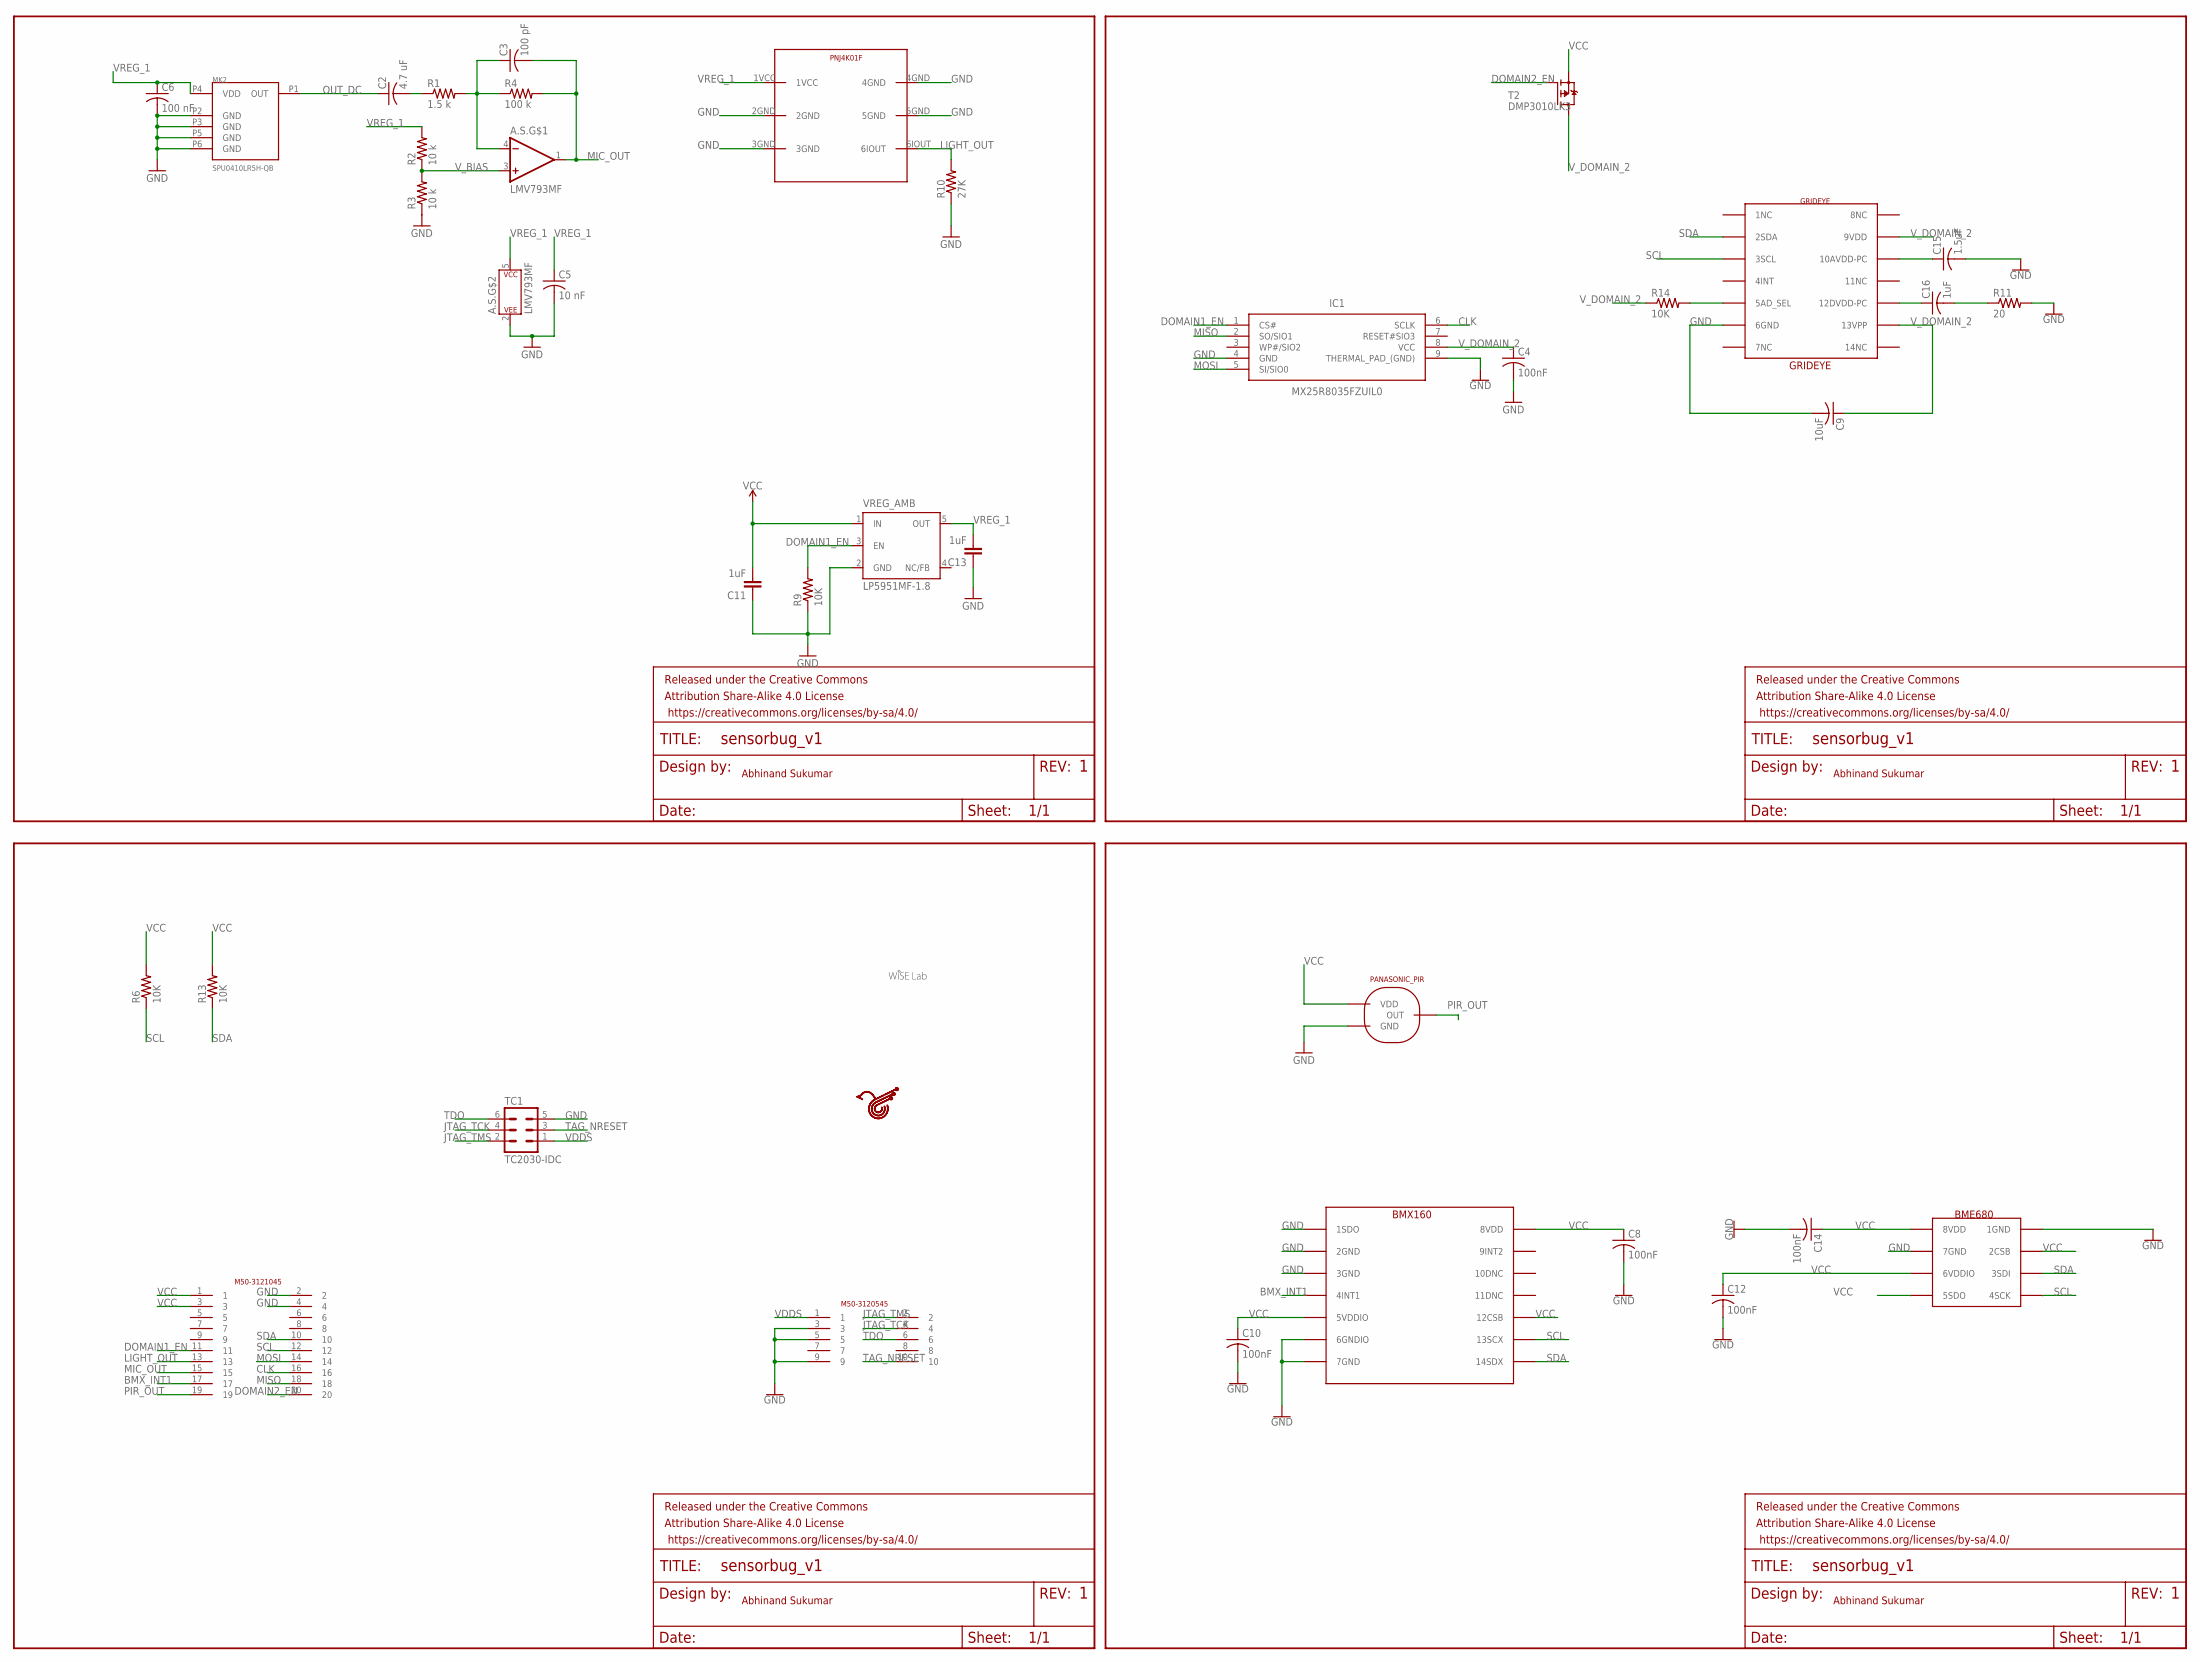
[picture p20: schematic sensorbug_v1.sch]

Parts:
A.S.: LMV793MF; SOT23-5
BME: BME680; BME680_LGA
BMX: BMX160; LGA
C2: 4.7 uF; C0603
C3: 100 pF; C0603
C4, C8, C10, C12, C14: 100nF; C0603
C5: 10 nF; C0603
C6: 100 nF; C0603
C9: 10uF; C0603
C11, C13, C16: 1uF; C0603
C15: 1.5uF; C0603
FRAME1, FRAME2, FRAME3, FRAME4: FRAME-LETTER; CREATIVE_COMMONS
GRIDEYE: GRIDEYE
IC1: MX25R8035FZUIL0; USON-8L
LIGHT: PNJ4K01F
MK2: SPU0410LR5H-QB
R1: 1.5 k; R0603
R2, R3: 10 k; R0603
R4: 100 k; R0603
R6, R9, R13, R14: 10K; R0603
R10: 27K; R0603
R11: 20; R0603
T2: DMP3010LK3; TO252
TC1: TC2030-IDC
U$2: WISELAB_LOGO-M; WISELAB_LOGO_M
U$3: EKMB1201112
U$4: M50-3121045
U$5: M50-3120545; M50-3100545
U$6: OPENCHIR_LOGO_PCB-M; OPENCHIRP_LOGO_M
VREG_AMB: LP5951MF-1.8; SOT23-DBV

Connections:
BMX_INT1: BMX.4INT1, U$4.17
CLK: IC1.6 (SCLK), U$4.16
DOMAIN1_EN: IC1.1 (CS#), R9.2, U$4.11, VREG_AMB.3 (EN)
DOMAIN2_EN: T2.1 (G), U$4.20
GND: A.S..2 (P$V-), BME.1GND, BME.7GND, BMX.1SDO, BMX.2GND, BMX.3GND, BMX.6GNDIO, BMX.7GND, C4.2, C5.2, C6.2, C8.2, C9.2, C10.2, C11.1, C12.2, C13.1, C14.2, C15.2, GRIDEYE.6 (6GND), IC1.4 (GND), IC1.9 (THERMAL_PAD_(GND)), LIGHT.2GND, LIGHT.3GND, LIGHT.4GND, LIGHT.5GND, MK2.P2 (GND), MK2.P3 (GND), MK2.P5 (GND), MK2.P6 (GND), R3.1, R9.1, R10.1, R11.2, TC1.5, U$3.GND, U$4.2, U$4.4, U$5.3, U$5.5, U$5.9, VREG_AMB.2 (GND)
JTAG_TCK: TC1.4, U$5.4
JTAG_TMS: TC1.2, U$5.2
LIGHT_OUT: LIGHT.6IOUT, R10.2, U$4.13
MIC_OUT: A.S..1 (OUT), C3.2, R4.2, U$4.15
MISO: IC1.2 (SO/SIO1), U$4.18
MOSI: IC1.5 (SI/SIO0), U$4.14
unnamed: C15.1, GRIDEYE.10 (10AVDD-PC)
unnamed: A.S..4 (-IN), C3.1, R1.2, R4.1
unnamed: C16.1, GRIDEYE.12 (12DVDD-PC)
unnamed: GRIDEYE.5 (5AD_SEL), R14.2
unnamed: C16.2, R11.1
OUT_AC: C2.2, R1.1
OUT_DC: C2.1, MK2.P1 (OUT)
PIR_OUT: U$3.OUT, U$4.19
SCL: BME.4SCK, BMX.13SCX, GRIDEYE.3 (3SCL), R6.1, U$4.12
SDA: BME.3SDI, BMX.14SDX, GRIDEYE.2 (2SDA), R13.1, U$4.10
TAG_NRESET: TC1.3, U$5.10
TDO: TC1.6, U$5.6
VCC: BME.2CSB, BME.5SDO, BME.6VDDIO, BME.8VDD, BMX.5VDDIO, BMX.8VDD, BMX.12CSB, C8.1, C10.1, C11.2, C12.1, C14.1, R6.2, R13.2, T2.2 (S), U$3.VDD, U$4.1, U$4.3, VREG_AMB.1 (IN)
VDDS: TC1.1, U$5.1
VREG_1: A.S..5 (P$V+), C5.1, C6.1, C13.2, LIGHT.1VCC, MK2.P4 (VDD), R2.2, VREG_AMB.5 (OUT)
V_BIAS: A.S..3 (+IN), R2.1, R3.2
V_DOMAIN_2: C4.1, C9.1, GRIDEYE.9 (9VDD), GRIDEYE.13 (13VPP), IC1.8 (VCC), R14.1, T2.3 (D)

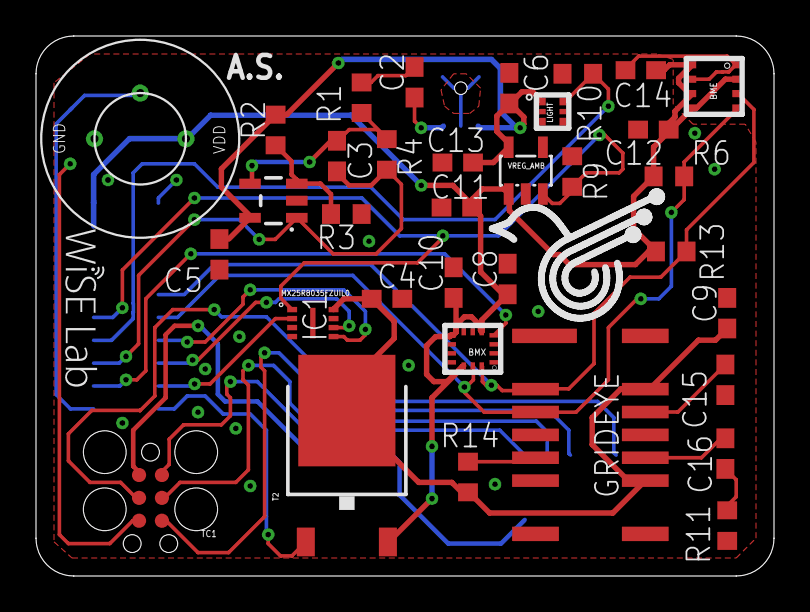
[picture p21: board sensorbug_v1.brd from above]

Board: 2 copper layers, 41.0 x 30.0 mm, 43 parts (1 on the bottom side), 28 nets.

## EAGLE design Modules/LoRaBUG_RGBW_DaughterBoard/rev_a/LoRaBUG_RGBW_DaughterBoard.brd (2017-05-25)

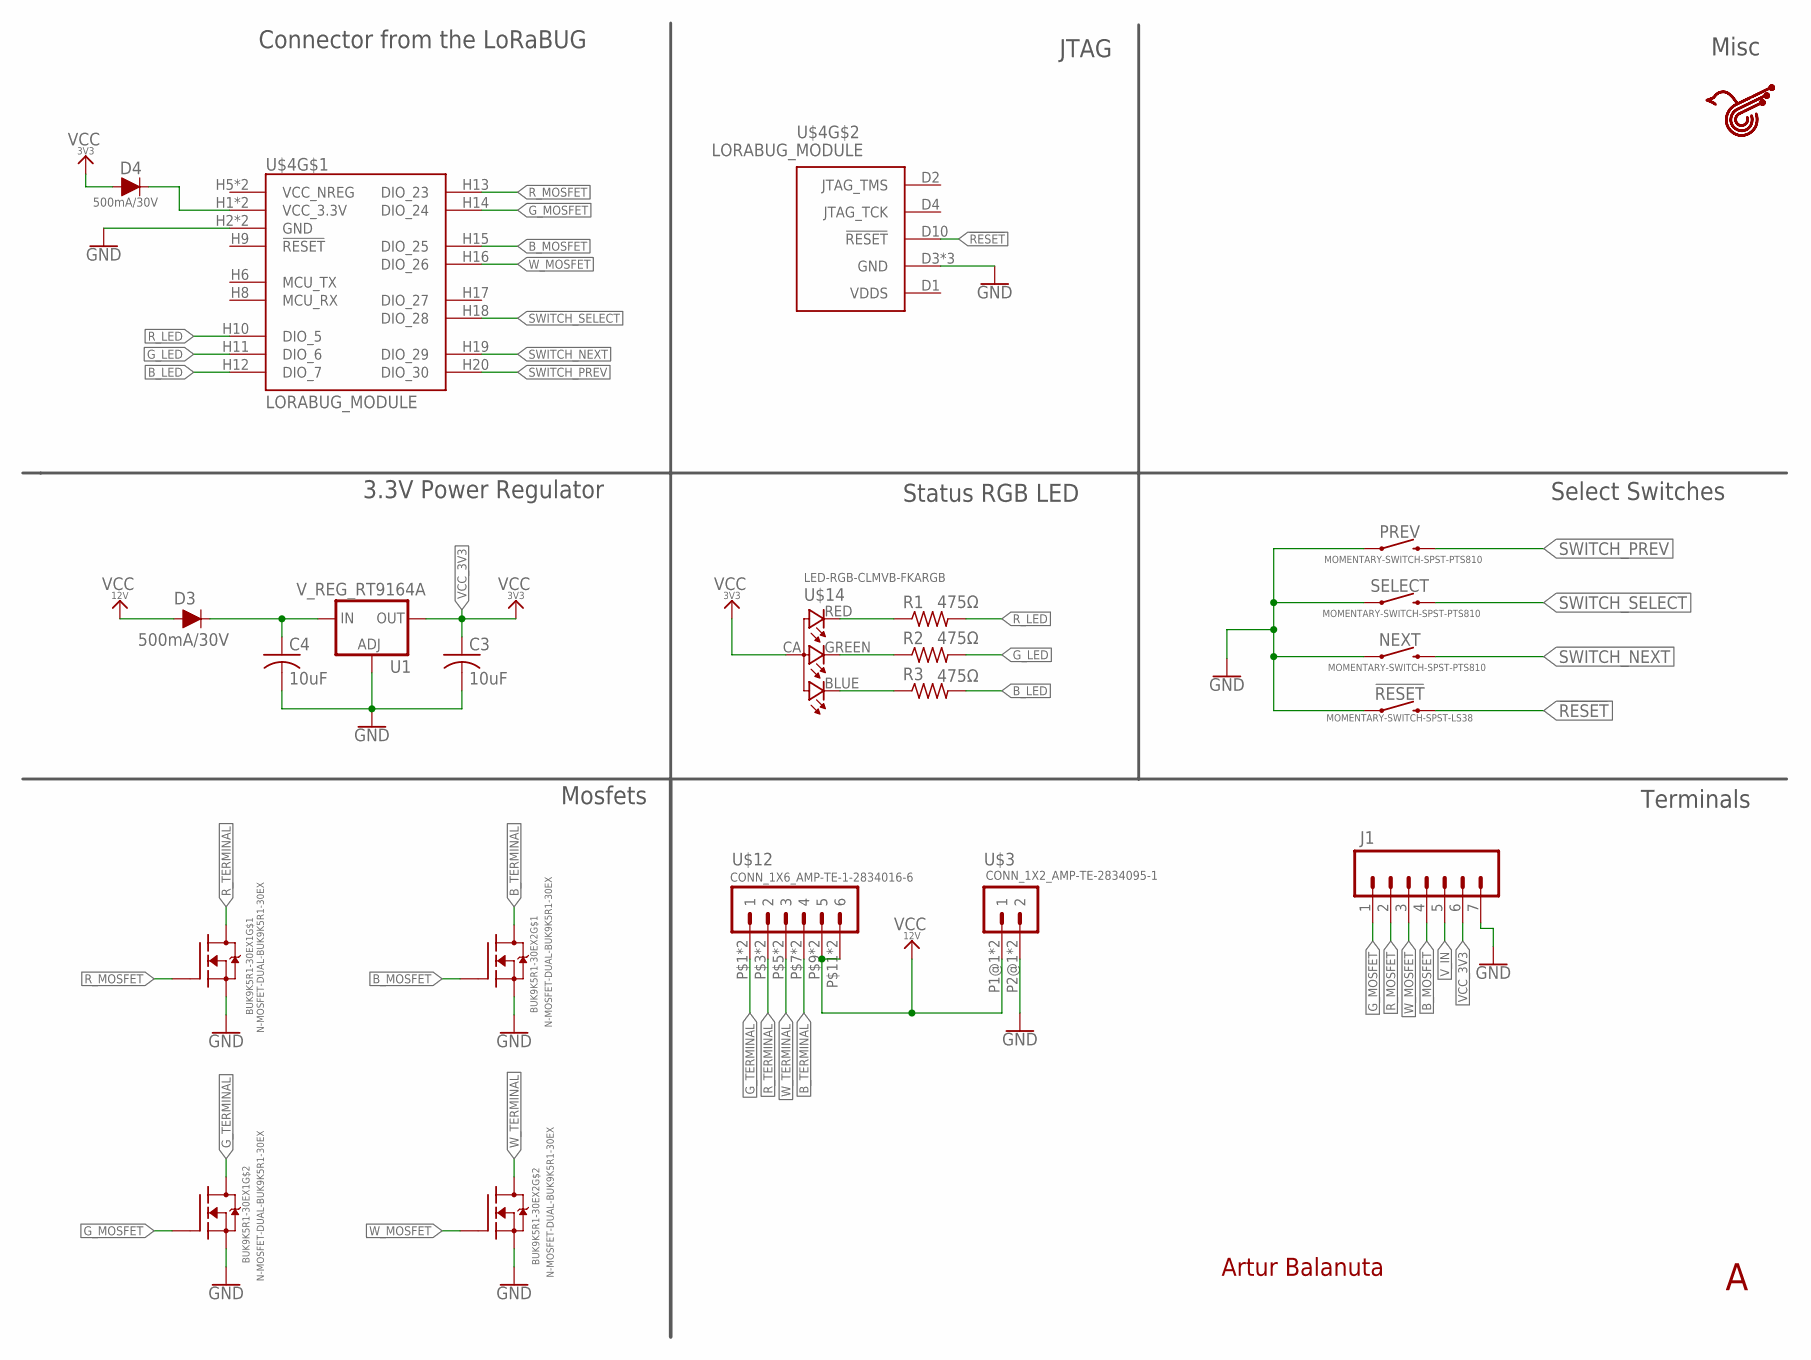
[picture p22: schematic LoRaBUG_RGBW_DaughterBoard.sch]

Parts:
!RESET: MOMENTARY-SWITCH-SPST-LS38; TACTILE_SWITCH_SMD_3.3X3.1MM_LS38
BUK9K5R1-30EX1, BUK9K5R1-30EX2: N-MOSFET-DUAL-BUK9K5R1-30EX; LFPAK56D
C3, C4: 10uF; C0603K
D3, D4: 500mA/30V; SOD-323
J1: CONN_07NO_SILK; 1X07_NO_SILK
NEXT: MOMENTARY-SWITCH-SPST-PTS810; TACTILE_SWITCH_SMD_4.2X3.2MM
PREV: MOMENTARY-SWITCH-SPST-PTS810; TACTILE_SWITCH_SMD_4.2X3.2MM
R1, R2, R3: 475Ω; R0603
SELECT: MOMENTARY-SWITCH-SPST-PTS810; TACTILE_SWITCH_SMD_4.2X3.2MM
U1: V_REG_RT9164A; SOT223
U$3: CONN_1X2_AMP-TE-2834095-1
U$4: LORABUG_MODULE
U$5: OPENCHIR_LOGO_PCB; OPENCHIRP_LOGO_S
U$12: CONN_1X6_AMP-TE-1-2834016-6
U$14: LED-RGB-CLMVB-FKARGB; PLCC4-2MM-RGB

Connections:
!RESET: !RESET.P$3 (2), !RESET.P$4 (2), U$4.D10 (!RESET)
B_LED: R3.2, U$4.H12 (DIO_7)
B_MOSFET: BUK9K5R1-30EX2.P$2 (G), J1.4, U$4.H15 (DIO_25)
B_TERMINAL: BUK9K5R1-30EX2.P$7 (D), BUK9K5R1-30EX2.P$8 (D), U$12.P$7 (4), U$12.P$8 (4)
GND: !RESET.P$1 (1), !RESET.P$2 (1), BUK9K5R1-30EX1.P$1 (S), BUK9K5R1-30EX1.P$3 (S), BUK9K5R1-30EX2.P$1 (S), BUK9K5R1-30EX2.P$3 (S), C3.2, C4.2, J1.7, NEXT.P$1 (1), NEXT.P$2 (1), PREV.P$1 (1), PREV.P$2 (1), SELECT.P$1 (1), SELECT.P$2 (1), U1.1 (ADJ), U$3.P2@1 (2), U$3.P2@2 (2), U$4.D3 (GND), U$4.D5 (GND), U$4.D9 (GND), U$4.H2 (GND), U$4.H4 (GND)
G_LED: R2.2, U$4.H11 (DIO_6)
G_MOSFET: BUK9K5R1-30EX1.P$4 (G), J1.1, U$4.H14 (DIO_24)
G_TERMINAL: BUK9K5R1-30EX1.P$5 (D), BUK9K5R1-30EX1.P$6 (D), U$12.P$1 (1), U$12.P$2 (1)
unnamed: R1.1, U$14.RED (4)
unnamed: R2.1, U$14.GREEN (3)
unnamed: R3.1, U$14.BLUE (2)
N_VIN: C4.1, D3.C, U1.3 (IN)
R_LED: R1.2, U$4.H10 (DIO_5)
R_MOSFET: BUK9K5R1-30EX1.P$2 (G), J1.2, U$4.H13 (DIO_23)
R_TERMINAL: BUK9K5R1-30EX1.P$7 (D), BUK9K5R1-30EX1.P$8 (D), U$12.P$3 (2), U$12.P$4 (2)
SWITCH_NEXT: NEXT.P$3 (2), NEXT.P$4 (2), U$4.H19 (DIO_29)
SWITCH_PREV: PREV.P$3 (2), PREV.P$4 (2), U$4.H20 (DIO_30)
SWITCH_SELECT: SELECT.P$3 (2), SELECT.P$4 (2), U$4.H18 (DIO_28)
VCC_3V3: C3.1, D4.A, J1.6, U1.2 (OUT), U1.4 (OUT), U$14.CA (1)
VCC_12V: D3.A, U$3.P1@1 (1), U$3.P1@2 (1), U$12.P$9 (5), U$12.P$10 (5), U$12.P$11 (6), U$12.P$12 (6)
VCC_NREG: U$4.H5 (VCC_NREG), U$4.H7 (VCC_NREG)
VDDS: U$4.D1 (VDDS)
V_IN: D4.C, J1.5, U$4.H1 (VCC_3.3V), U$4.H3 (VCC_3.3V)
W_MOSFET: BUK9K5R1-30EX2.P$4 (G), J1.3, U$4.H16 (DIO_26)
W_TERMINAL: BUK9K5R1-30EX2.P$5 (D), BUK9K5R1-30EX2.P$6 (D), U$12.P$5 (3), U$12.P$6 (3)

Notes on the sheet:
Connector from the LoRaBUG
Artur Balanuta
3.3V Power Regulator
Status RGB LED
Select Switches
Terminals
Mosfets
JTAG
Misc

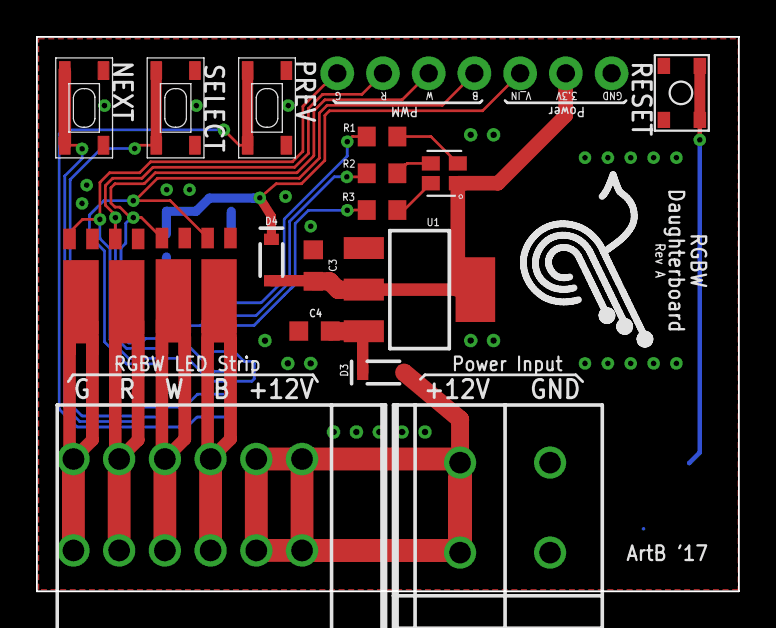
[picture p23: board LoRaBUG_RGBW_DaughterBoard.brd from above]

Board: 2 copper layers, 39.0 x 30.8 mm, 20 parts (0 on the bottom side), 24 nets.

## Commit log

2016-06-03 Semtech SX1276 schematic and initial work on the TI CC2650 schematic.
    [CC2650MCURadio.SchDoc, CC26XX_7X7_DIFF_Library.SchLib, CC26xx_7x7_Diff.PcbLib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]
2016-06-03 Fixed missing Semtech and TI libraries
    [LoRaBugBoard.PrjPcb]
2016-06-03 Fixed TI chip - changed from CC13xx to CC26xx. Completed RF side of CC2650 schematic.
    [CC2650MCURadio.SchDoc]
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2016-06-14 Recovered and updated SX1276Radio schematic
    [SX1276Radio.SchDoc]
2016-06-14 Modified Adwait's board lib to not include antenna and outline
    [Boards.PCBLIB]
2016-06-14 Removed miscellaneous component_1 from TI library
    [CC26XX_7X7_DIFF_Library.SchLib]
2016-06-14 Updates to schematics and project
    [CC2650MCURadio.SchDoc, ExtraComponents.PcbLib, ExtraComponents.SchLib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]
2016-06-14 Base PCB board design. No elements placed.
    [PCBFireflyCase.PcbDoc]
2016-06-14 Progress laying out PCB
    [PCBFireflyCaseTest.PcbDoc]
2016-06-17 More routing and general progress
    [ExtraComponents.PcbLib, ExtraComponents.SchLib, LoRaBugBoard.PrjPcb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]
2016-06-21 Work in progress. * Fixed missing VCC_ANA * Added some 3D models * Changed/deleted buttons * Simplified power * Removed small header * Shrunk FTDI decoup caps * Routed more * More that I can't recall
    [Boards.PCBLIB, Boards.SCHLIB, CC2650MCURadio.SchDoc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]
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2016-06-22 Unified Connectors Library and added 3D models
    [Boards.PCBLIB, Boards.SCHLIB, Connectors.PcbLib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]
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2016-06-22 Big changes and corrections
    [CC2650MCURadio.SchDoc, ExtraComponents.PcbLib, ExtraComponents.SchLib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]
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2016-06-23 Corrected errors in schematic and routing progress. Nearly finished routing.
    [Connectors.PcbLib, FTDIUSB.SchDoc, Main.SchDoc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]
2016-06-24 Second time redoing the new RFI Shield 26.21x26.21mm
    [ExtraComponents.PcbLib, ExtraComponents.SchLib]
2016-06-24 Repositioned the RFI Shield origin
    [ExtraComponents.PcbLib]
2016-06-25 Added in new RFI shield that I do not currently use anymore.
    [WE-SHC-SMD.Schlib, WE-SHC-THT.Schlib, WE-SHC.PcbLib]
2016-06-25 Modified schematic to fit PCB a bit and progress routing
    [CC2650MCURadio.SchDoc, LoRaBugBoard.PrjPcb, Main.SchDoc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]
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2016-06-27 Changed RFI shield to use pads instead of polygon fills. This allows the ground plane fill to attach itself to the contacts.
    [ExtraComponents.PcbLib, ExtraComponents.SchLib]
2016-06-27 Bug fixes in schematic. One big one is VDD* vs VSS* labeling conflict with SX schematic
    [CC2650MCURadio.SchDoc, Main.SchDoc, Peripherals.SchDoc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]
2016-06-27 Disconnect SPI from header
    [Main.SchDoc]
2016-06-27 Partial surgery underway. One bottom of CC2650 must be routed.
    [PCBFireflyCase.PcbDoc]
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2016-06-28 Before major surgery on the PCB
    [PCBFireflyCase.PcbDoc]
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2016-06-29 Added surface mount SMA connector back into the CC2650 schematic
    [CC2650MCURadio.SchDoc]
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2016-06-29 Added in an inverted F antenna to ExtraComponents with no solder mask or paste.
    [ExtraComponents.PcbLib]
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2016-06-29 Updated CC2650 to use new inverted F antenna
    [CC2650MCURadio.SchDoc]
2016-06-29 Fixed voltage unregulated disconnect in PCB. Before reshaping board to include triangle corners
    [PCBFireflyCase.PcbDoc]
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2016-07-01 Switched LED control lines. No copper constraint violations.
    [LoRaBugBoard.PrjPcb, Main.SchDoc, PCBFireflyCase.PcbDoc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]
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2016-07-05 Regenerated Gerber files with new mechanical layer 1
    [LoRaBugBoard.PrjPcb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]
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2016-08-03 Fixed button NC/NO pin error. Added proper fiducials to schematic.
    [ExtraComponents.PcbLib, ExtraComponents.SchLib, LoRaBugBoard.PrjPcb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]
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2016-09-16 Added new Dual Mosfet, VREG, and Diodes to ExtraComponents
    [ExtraComponents.PcbLib, ExtraComponents.SchLib]
2016-09-16 Simplified mosfets for LED to single dual mosfet chip
    [Peripherals.SchDoc]
2016-09-16 Fixed reverse power leakage in VREG design and increased power output of VREG
    [Main.SchDoc]
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2016-09-20 Changed VREG mosfet switch to the dual mosfet due to size constraints
    [Main.SchDoc]
2016-09-21 Swapped LED connections on dual mosfet for better PCB layout Cleaned up schematics
    [Main.SchDoc, Peripherals.SchDoc]
2016-09-21 Finished vreg power leakage fix
2016-09-21 Removed FTDI lib from libraries, since FTDI chip is in ExtraComponents lib
    [LoRaBugBoard.PrjPcb]
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2016-09-21 Added new footprint for FTDI with long leads. Changed FTDI module schematic to use new footprint
    [ExtraComponents.PcbLib, ExtraComponents.SchLib, FTDIUSB.SchDoc]
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2016-09-21 Merged FTDI Fixed PCB layout into the PCBFireflyCaseV2
    [LoRaBugBoard.PrjPcb]
2016-09-21 Changed R20 from 0402 to 0603 to consolidate components
    [Peripherals.SchDoc]
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2016-10-14 Changed R17 and R18 to be specific for LEDs D1 and D2
    [BOM.xls]
2016-10-14 Change TICC2650 to the cheaper higher quantity MCU package, the CC2650F128RGZR instead of CC2650F128RGZT.
    [BOM.xls]
2016-10-14 Changed crystal cap to 10pF. Changed sorted LoRa module sheet to take precedence.
    [BOM.xls]
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2016-10-28 Changed note about reverse leakage current
2016-10-29 Switched diode to new 0 leakage version and organized a bit
    [BOM.xls]
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2016-10-31 Added RFI can options to Hardware sheet in BOM
    [BOM.xls]
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2016-11-16 Added new 2x10 1.27mm SMD header to Connectors library
    [Connectors.PcbLib, Connectors.SchLib]
2016-11-16 Added notes and renamed nets in CC1650 module
    [CC2650MCURadio.SchDoc]
2016-11-16 Rewired a few nets in SX1276 module in an attempt to fix Altium's net coloring glitch
    [SX1276Radio.SchDoc]
2016-11-16 Adjusted for peripherals module for new 1.27mm 2x10 header * Changed button to active low * Removed I2C pullups * Added system uart tx/rx to header * Added voltage non-regulated to header
    [Peripherals.SchDoc]
2016-11-16 Pulled power subsystem components out of Main schematic and placed them in new Power schematic * We now explicitly deal with VCC_NREG for non-regulated power
    [Main.SchDoc, Power.SchDoc]
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2016-11-16 Updated Revision count Document Parameter to 3 for all schematics
    [CC2650MCURadio.SchDoc, FTDIUSB.SchDoc, Main.SchDoc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]
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2016-11-17 Updated BOM with new header and Power naming scheme
    [BOM.xls]
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2016-11-17 Added 2x5 1.27mm header to Connectors library with low-profile header 3D model
    [Connectors.PcbLib, Connectors.SchLib]
2016-11-17 Final edits to schematic and PCB layout for V3
    [CC2650MCURadio.SchDoc, LoRaBugBoard.PrjPcb, Peripherals.SchDoc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]
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2016-11-18 Minor corrections and improved readability of BOM.xls
    [BOM.xls]
2016-11-18 Added script to trigger bootloader on device reset
2016-11-21 Fixed R19 incorrect Part Number and moved D3 up sheet
    [BOM.xls]
2016-12-08 Made changes for v3.1 in SX1276 radio and PCB
    [LoRaBugBoard.PrjPcb, SX1276Radio.SchDoc]
2016-12-08 Updated documentation and schematic documentaion with V3.1 changes
    [SX1276Radio.SchDoc]
2016-12-08 Generated all fabrication and PDF files for V3.1 Archived V3.0
    [LoRaBugBoard.PrjPcb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]
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2017-01-06 Critical Change. Changed LoRa modem crystal caps to 15pF
    [BOM.xls]
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2017-03-22 Striked the Abracon antenna out, since it doesn't work well
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2017-07-12 Added Info and V1 Directories
    Info has a pdf with schematic and board layout. V1 has the schematic,
    board, and gerber files.
    [sensorbug_v1.brd, sensorbug_v1.sch]
2017-07-26 Fixed Light Sensor Output
    Previous light sensor output pin did not have ADC capabilities.
    Interchanged DOMAIN1_EN and LIGHT_OUT.
    [sensorbug_v1.brd, sensorbug_v1.sch]
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2019-02-25 Changed FTDI schematic 3V3 output to a Power pin
    [ExtraComponents.SchLib]
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

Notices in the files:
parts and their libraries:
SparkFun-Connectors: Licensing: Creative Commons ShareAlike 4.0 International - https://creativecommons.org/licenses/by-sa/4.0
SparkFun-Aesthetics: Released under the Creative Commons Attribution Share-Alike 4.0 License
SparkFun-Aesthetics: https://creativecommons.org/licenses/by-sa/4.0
